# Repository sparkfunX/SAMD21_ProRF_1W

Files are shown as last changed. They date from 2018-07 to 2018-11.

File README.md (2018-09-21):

SparkFun SAMD21 Pro RF 1W 
========================================

SparkFun SAMD21 Pro RF 1W

[*SparkFun SAMD21 Pro RF 1W  (SPX-14984)*](https://www.sparkfun.com/products/14984)

LoRa stands for 'Long-Range,' referring to a modulation technique whose specialty is low power transmission of small data packets -- perfect for Internet of Things applications. Using either point-to-point radio or LoRaWAN you can send data from a node in a remote location back to your base station to check in on sensors or track equipment. Communication is possible in the other direction as well to send commands or control actuators!

Like the [LoRa®-enabled SparkX Pro RF](https://www.sparkfun.com/products/14785) this board is based on the Semtech SX1276 transceiver, but the module boasts a whopping 1W output power. All that extra oomph makes it possible to send small messages up to 9 miles using common rubber-duck type antennas. 

In addition to more transmission power the SparkX SAMD21 ProRF 1W gets more computational power courtesy of the SAMD21 microcontroller running at 48 MHz. We used the additional GPIO pins to permanently enable LoRaWAN signals. This means more pins for you to connect to sensors and actuators, even when connecting to a LoRaWAN network like [The Things Network](https://console.thethingsnetwork.org/). 

SparkFun labored with love to create this code. Feel like supporting open source hardware? 
Buy a [board](https://www.sparkfun.com/products/14984) from SparkFun!

Repository Contents
-------------------

* **/Documents** - Datasheets
* **/Hardware** - Eagle design files (.brd, .sch)

License Information
-------------------

This product is _**open source**_! 

If you have any questions or concerns on licensing, please contact techsupport@sparkfun.com.

Please use, reuse, and modify these files as you see fit. Please maintain attribution to SparkFun Electronics and release any derivative under the same license.

Distributed as-is; no warranty is given.

- Your friends at SparkFun.

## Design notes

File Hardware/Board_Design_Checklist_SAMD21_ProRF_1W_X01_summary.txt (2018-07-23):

1) Is there a SparkFun Logo? [YES]
comment: SPARKX logo

2) Is the board dimension outline correct thickness? (0.008 inch) [NO]
comment: 0.006

3) Are opposing 0.1 inch headers spaced to fit into a breadboard? [NO]
comment: Too wide, 90 degree rotated header section

4) Is the LED color standard followed? (red for power, blue for STAT, green for TX, yellow for RX) [YES]
comment: Used blue for lipo charge status

5) Does it pass DRC with top/bottom keepout layers on? [NO]
comment: Approved keepout errors

6) Are there airwires after ratsnest? [YES]
comment: Antenna, to be routed

7) Is the SparkFun Logo on the board? [YES]
comment: SparkX

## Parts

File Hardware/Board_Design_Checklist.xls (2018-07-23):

SECTION | CHECK | STATUS | DEPENDANCY | CORRECT ANSWER | USER | USER-ANSWER | COMMENT | WIKI_LINK
Macro | is_revision | 0
Macro | has_pth | 0
Macro | has_i2c | 0
Macro | has_SPI | 0
Macro | has_1x6_ftdi_header | 0
Macro | has_jumpers | 0
Macro | has_leds | 0
Macro | has_vreg | 0
Macro | has_QFN | 0
Macro | has_SS | 0
Macro | has_multi_sheet | 0
Macro | is_kit | 0
Macro | has_serial | 0
Macro | is_4layer | 0
Macro | has_milling | 0
Macro | has_switchorbutton | 0
Macro | has_collaboration | 0
General | Are the part libraries consistent with eagle github repo? |  |  | YES
Schematic | Is the proper frame with CC attribution used? |  |  | YES
Schematic | Are all schematic objects inside the frame? |  |  | YES
Schematic | Is there a SparkFun Logo? |  |  | YES
Schematic | Is there an OSHW logo? |  |  | YES
Schematic | Is proper attribution given to the original designer? |  |  | YES
Schematic | Is "Revised by: " and the reviser's name present? |  | 2 | YES
Schematic | Are NET labels the correct FLAG type? |  |  | YES
Schematic | Have all nets been drawn straight out from pin connections at least one grid space? |  |  | YES
Schematic | Are all net lines 0.006 inch? |  |  | YES
Schematic | Are there any 4-way junctions? |  |  | NO
Schematic | Are junction dots used for all 3-wire connections? |  |  | YES
Schematic | Are the fiducials in the lower right corner? |  |  | YES
Schematic | Are the standoffs in the lower right corner? |  |  | YES
Schematic | Are dashed grey lines ('info' eagle layer 97) used to clearly separate different areas? |  |  | YES
Schematic | Is the version number correct? |  |  | YES
Schematic | Is the version number included on all sheets? |  | 12 | YES
Schematic | Do all GND connections use the GND symbol (oriented downward)? |  |  | YES
Schematic | Do all VCC connections use the VCC symbol (oriented upward)? |  |  | YES
Schematic | Is the VCC range clearly labeled? |  |  | YES
Schematic | Are any jumpers labeled clearly by their function and possible settings? |  | 7 | YES
Schematic | Are any appropriate warnings (voltage conversion, sensitive I/O) labeled? |  |  | YES
Schematic | Are any notes of two versions of the board in the schematic (3.3V regulator vs 5V regulator)? |  |  | YES
Schematic | Do any part names have '/.~' in them? (Multiple sheets) |  | 12 | NO
Schematic | Have you verified that the BOM in Sparkle is accurate (also checking for PROD_ID, NAME, VALUE, PREFIX)? |  |  | YES
Schematic | Do any parts have unnecessary values (Eagle has autoset the package as the value)? |  |  | NO
Schematic | Regarding the voltage regulator, is the input on the LEFT, and the output on the RIGHT? |  | 9 | YES
Schematic | Is the I2C address in the schematic? |  | 4 | YES
Schematic | Is the I2C pin order correct (GND/VCC/SDA/CLK) and did you consider using a Qwiic connector? |  | 4 | YES |  |  |  | https://wiki.sparkfun.com/index.php?title=Eagle_Rules#Pin_Out.2FConnection_Orientation
Schematic | Is the I2C pull-up resistor isolation jumper present? |  | 4 | YES |  |  |  | https://wiki.sparkfun.com/index.php?title=Eagle_Rules#Component_Placement
Schematic | Is the SPI pull-up resistor for Chip Select present? |  | 5 | YES |  |  |  | https://wiki.sparkfun.com/index.php?title=Eagle_Rules#Component_Placement
Schematic | Is the MISO tri-state buffer included? |  | 5 | YES |  |  |  | https://wiki.sparkfun.com/index.php?title=Eagle_Rules#Component_Placement
Board | If this is a Qwiic board, does it follow the design guidelines for Qwiic boards in the Wiki? |  | 4 | YES |  |  |  | https://wiki.sparkfun.com/index.php?title=Qwiic_Standard
Board | If this board is not branded as a Qwicc board, but contains a Qwiic connector, is the connector labeled with “QWIIC” text silk? |  | 4
Board | Are the inner layers on the correct eagle layers? (2 and 15) |  | 15 | YES |  |  |  | https://wiki.sparkfun.com/index.php?title=Eagle_Rules#Board_Creation.2C_Outline
Board | Does your 4 layer board include '1' '2' '3' '4' in the copper of each layer? |  | 15 | YES |  |  |  | https://wiki.sparkfun.com/index.php?title=Eagle_Rules#Board_Creation.2C_Outline
Board | Is the bottom left corner board dimensions at 0,0? |  |  | YES |  |  |  | https://wiki.sparkfun.com/index.php?title=Eagle_Rules#Board_Creation.2C_Outline
Board | Is the board dimension outline correct thickness? (0.008 inch) |  |  | YES |  |  |  | https://wiki.sparkfun.com/index.php?title=Eagle_Rules#Board_Creation.2C_Outline
Board | If this requires very precise dimensions (e.g. USB stick), did you consider GP's tolerances? (dimension=5mils, Vscore=10mils) |  |  |  |  |  |  | https://wiki.sparkfun.com/index.php?title=Eagle_Rules#Fab_house_Tolerances
Board | Are 0.1 inch headers lined up on 0.1 inch grid? |  |  | YES |  |  |  | https://wiki.sparkfun.com/index.php?title=Eagle_Rules#Board_Creation.2C_Outline
Board | Are opposing 0.1 inch headers spaced to fit into a breadboard? |  |  | YES |  |  |  | https://wiki.sparkfun.com/index.php?title=Eagle_Rules#Board_Creation.2C_Outline
Board | Do all testpoints have a separation of at least 0.1 inch (preferably placed on a 0.05 inch grid)? |  |  | YES |  |  |  | https://wiki.sparkfun.com/index.php?title=Eagle_Rules#Board_Creation.2C_Outline
Board | Does the board have standoffs? |  |  | YES |  |  |  | https://wiki.sparkfun.com/index.php?title=Eagle_Rules#Board_Creation.2C_Outline
Board | Can standoffs/screws be used clear of other parts? |  |  | YES |  |  |  | https://wiki.sparkfun.com/index.php?title=Eagle_Rules#Board_Creation.2C_Outline
Board | Is the FTDI connector accessible (do neighboring parts allow enough space to clear each side)? |  | 6 | YES |  |  |  | https://wiki.sparkfun.com/index.php?title=Eagle_Rules#Pin_Out.2FConnection_Orientation
Board | Is the FTDI connector oriented so the FTDI breakout can be slid on properly (IC side up, header side down)? |  | 6 | YES |  |  |  | https://wiki.sparkfun.com/index.php?title=Eagle_Rules#Pin_Out.2FConnection_Orientation
Board | Are vias tented correctly? |  |  | YES |  |  |  | https://wiki.sparkfun.com/index.php?title=Eagle_Rules#Trace_Routing.2C_Polygon_Pours.2C_and_Vias
Board | If possible, are all overhanging parts on the same edge of the board (this helps with panelization)? |  |  | YES |  |  |  | https://wiki.sparkfun.com/index.php?title=Eagle_Rules#Pin_Out.2FConnection_Orientation
Board | If this design requires special ordering or production assembly instructions, have the symbols/packages been added with notes? (PCB thickness, humidity sensitivity, etc.) |  |  | YES
Board | Are any vias intended to be used as PTH headers (they shouldn't be)? |  |  | NO |  |  |  | https://wiki.sparkfun.com/index.php?title=Eagle_Rules#Trace_Routing.2C_Polygon_Pours.2C_and_Vias
Board | Is the LED color standard followed? (red for power, blue for STAT, green for TX, yellow for RX) |  | 8 | YES |  |  |  | https://wiki.sparkfun.com/index.php?title=Eagle_Rules#Component_Placement
Board | Do parts that need selective solder have a planned nozzle path on layer 48? (valid widths: 0.178", 0,263", 0.354") |  | 11 | YES |  |  |  | https://wiki.sparkfun.com/index.php?title=Eagle_Rules#Selective_Soldering
Board | As best as possible, do all SMD pads have only 1 trace entering the pad? |  |  | YES |  |  |  | https://wiki.sparkfun.com/index.php?title=Eagle_Rules#PCB_Layout
Board | Are there any natural bridges on SMT components? |  |  | NO |  |  |  | https://wiki.sparkfun.com/index.php?title=Eagle_Rules#PCB_Layout
Board | Do V-Scored edges have a 50 mil border free of pads and parts (to prevent cracking on separation)? |  |  | YES
Board | Is the direction of TX/RX serial connections correct? |  | 14 | YES
Board | Are the TX/RX pins of the FTDI properly connected? |  | 6 | YES
Board | Is trace routing up to spec? (to/from center-points, straight lines, 45 angles, 'T' intersections, no right angles or acid traps) |  |  | YES |  |  |  | https://wiki.sparkfun.com/index.php?title=Eagle_Rules#PCB_Layout
Board | For thermal considerations, are traces routed away from the component, with symmetrical routing? |  | 10 | YES
Board | Do all footprints pass 1:1 check? (Applies mostly to new components) |  |  | YES
Board | Are all QFN components with 6 or more leads 75 percent pasted on lead pads? (May be contended depending on performance) |  | 10 | YES |  |  |  | https://wiki.sparkfun.com/index.php?title=Eagle_Rules#Footprints.2FPackages
Board | Are center pad cream apertures properly reduced? (50-75% paste is good) |  | 10 | YES |  |  |  | https://wiki.sparkfun.com/index.php?title=Eagle_Rules#Footprints.2FPackages
Board | Is there solder mask between pads on of 11 mil separation and greater? |  |  | YES |  |  |  | https://wiki.sparkfun.com/index.php?title=Eagle_Rules#Fab_house_Tolerances
Board | Is there a correct version number in the copper (aligned properly with the edge of the PCB)? |  |  | YES
Board | Are there fiducials on both the TOP and BOTTOM of the board? |  |  | YES
Board | Does it pass DRC with top/bottom keepout layers on? |  |  | YES
Board | If there are any DRC errors, have they all been approved? |  |  | YES
Board | Are there airwires after ratsnest? |  |  | NO
Board | Are all KIT PTH parts on the correct side with correct masking (e.g. the TSTOP or BSTOP expose the correct side) |  | 13 | YES
Documentation | Is there a note for a 4-layer board (on tDOCU)? |  | 15 | YES
Documentation | Do all packages have NAME and VALUE? |  |  | YES
Documentation | Is there a note for a board thickness other than 0.63 inch?
Documentation | Are measurements included for outer dimension and standoffs (Eagle layer 47)? |  |  | YES
Documentation | Are the board dimensions on 0.05 inch or 0.01 inch grid? |  |  | YES
Documentation | Are routed-out areas labeled 'ROUTE OUT' (on dimension)? |  | 16 | YES
Documentation | Is the CC/Design By included in tDocu? |  |  | YES
Documentation | Is the designer name included in tDocu? |  |  | YES
Documentation | Is 'Revised by:' and 'Revisor Name' included in tDocu? |  | 2 | YES
Silkscreen/Labeling | Is the name of the board on the board? |  |  | YES |  |  |  | https://wiki.sparkfun.com/index.php?title=Eagle_Rules#PCB_Silk
Silkscreen/Labeling | Do all footprints have 0.008 inch silk footprint? |  |  | YES
Silkscreen/Labeling | Are all LEDs labeled with their purpose? |  | 8 | YES
Silkscreen/Labeling | Are all PTHs (aka connectors) clearly labeled with their purpose on both sides of the board? |  |  | YES
Silkscreen/Labeling | Are battery terminals labeled +/- correctly? |  |  | YES
Silkscreen/Labeling | Are all jumpers labeled? |  | 7 | YES
Silkscreen/Labeling | If it is a 3-way jumper, is there a label on each side of the jumper? |  | 7 | YES
Silkscreen/Labeling | Are all switches/buttons labeled properly? |  | 17 | YES
Silkscreen/Labeling | Are active low pins labeled clearly? |  |  | YES
Silkscreen/Labeling | Are all labels lined up properly? |  |  | YES
Silkscreen/Labeling | Is all text at least 0.032 inch, 15 percent radio, and vector? |  |  | YES
Silkscreen/Labeling | Does the FTDI connector have BLK/GRN labeled correctly? |  | 6 | YES
Silkscreen/Labeling | Do all components have polarity or pin 1 labeled? |  |  | YES
Silkscreen/Labeling | Is the polarity label outside of the package for visibility after part population? |  |  | YES
Silkscreen/Labeling | Are there check labels for different versions of the board (3.3V vs 5V)? |  |  | YES
Silkscreen/Labeling | Is the SparkFun Logo on the board? |  |  | YES
Silkscreen/Labeling | Is the OSHW logo on the board? |  |  | YES
Silkscreen/Labeling | Is the firmware opensource? If not, did you omit the OSHW Logo? |  | 18 | YES
Silkscreen/Labeling | Is any silkscreen overlaid on vias? |  |  | NO
Silkscreen/Labeling | Is there a URL for any kits or unique boards?
Special | Are dimension lines properly spaced for V-scoring (lines on a 0.020” center-to-center spacing)?
Special | On white solder mask pcbs, is there any solder mask between leads on large SMT components?
Special | Are axes labeled correctly?
Special | Are there warning labels for high voltage areas?
END | Thanks for flying with us. Have a great day!!

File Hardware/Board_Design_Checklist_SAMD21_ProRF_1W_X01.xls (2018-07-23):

SECTION | CHECK | STATUS | DEPENDANCY | CORRECT ANSWER | USER | USER-ANSWER | COMMENT | WIKI_LINK
Macro | is_revision | 0
Macro | has_pth | 0
Macro | has_i2c | 0
Macro | has_SPI | 1
Macro | has_1x6_ftdi_header | 0
Macro | has_jumpers | 0
Macro | has_leds | 1
Macro | has_vreg | 1
Macro | has_QFN | 0
Macro | has_SS | 0
Macro | has_multi_sheet | 0
Macro | is_kit | 0
Macro | has_serial | 1
Macro | is_4layer | 0
Macro | has_milling | 0
Macro | has_switchorbutton | 1
Macro | has_collaboration | 0
General | Are the part libraries consistent with eagle github repo? |  |  | YES | owen.lyke | YES
Schematic | Is the proper frame with CC attribution used? |  |  | YES | owen.lyke | YES
Schematic | Are all schematic objects inside the frame? |  |  | YES | owen.lyke | YES
Schematic | Is there a SparkFun Logo? |  |  | YES | owen.lyke | YES | SPARKX logo
Schematic | Is there an OSHW logo? |  |  | YES | owen.lyke | YES
Schematic | Is proper attribution given to the original designer? |  |  | YES | owen.lyke | YES
Schematic | Is "Revised by: " and the reviser's name present? |  | 2 | YES | owen.lyke | *n/a*
Schematic | Are NET labels the correct FLAG type? |  |  | YES | owen.lyke | YES
Schematic | Have all nets been drawn straight out from pin connections at least one grid space? |  |  | YES | owen.lyke | YES
Schematic | Are all net lines 0.006 inch? |  |  | YES | owen.lyke | YES
Schematic | Are there any 4-way junctions? |  |  | NO | owen.lyke | YES
Schematic | Are junction dots used for all 3-wire connections? |  |  | YES | owen.lyke | YES
Schematic | Are the fiducials in the lower right corner? |  |  | YES | owen.lyke | YES
Schematic | Are the standoffs in the lower right corner? |  |  | YES | owen.lyke | NO
Schematic | Are dashed grey lines ('info' eagle layer 97) used to clearly separate different areas? |  |  | YES | owen.lyke | YES
Schematic | Is the version number correct? |  |  | YES | owen.lyke | YES
Schematic | Is the version number included on all sheets? |  | 12 | YES | owen.lyke | *n/a*
Schematic | Do all GND connections use the GND symbol (oriented downward)? |  |  | YES | owen.lyke | YES
Schematic | Do all VCC connections use the VCC symbol (oriented upward)? |  |  | YES | owen.lyke | YES
Schematic | Is the VCC range clearly labeled? |  |  | YES | owen.lyke | YES
Schematic | Are any jumpers labeled clearly by their function and possible settings? |  | 7 | YES | owen.lyke | *n/a*
Schematic | Are any appropriate warnings (voltage conversion, sensitive I/O) labeled? |  |  | YES | owen.lyke | YES
Schematic | Are any notes of two versions of the board in the schematic (3.3V regulator vs 5V regulator)? |  |  | YES | owen.lyke | n/a
Schematic | Do any part names have '/.~' in them? (Multiple sheets) |  | 12 | NO | owen.lyke | *n/a*
Schematic | Have you verified that the BOM in Sparkle is accurate (also checking for PROD_ID, NAME, VALUE, PREFIX)? |  |  | YES | owen.lyke | n/a
Schematic | Do any parts have unnecessary values (Eagle has autoset the package as the value)? |  |  | NO | owen.lyke | NO
Schematic | Regarding the voltage regulator, is the input on the LEFT, and the output on the RIGHT? |  | 9 | YES | owen.lyke | YES
Schematic | Is the I2C address in the schematic? |  | 4 | YES | owen.lyke | *n/a*
Schematic | Is the I2C pin order correct (GND/VCC/SDA/CLK) and did you consider using a Qwiic connector? |  | 4 | YES | owen.lyke | *n/a* |  | https://wiki.sparkfun.com/index.php?title=Eagle_Rules#Pin_Out.2FConnection_Orientation
Schematic | Is the I2C pull-up resistor isolation jumper present? |  | 4 | YES | owen.lyke | *n/a* |  | https://wiki.sparkfun.com/index.php?title=Eagle_Rules#Component_Placement
Schematic | Is the SPI pull-up resistor for Chip Select present? |  | 5 | YES | owen.lyke | YES |  | https://wiki.sparkfun.com/index.php?title=Eagle_Rules#Component_Placement
Schematic | Is the MISO tri-state buffer included? |  | 5 | YES | owen.lyke | NO |  | https://wiki.sparkfun.com/index.php?title=Eagle_Rules#Component_Placement
Board | If this is a Qwiic board, does it follow the design guidelines for Qwiic boards in the Wiki? |  | 4 | YES | owen.lyke | *n/a* |  | https://wiki.sparkfun.com/index.php?title=Qwiic_Standard
Board | If this board is not branded as a Qwicc board, but contains a Qwiic connector, is the connector labeled with “QWIIC” text silk? |  | 4 |  | owen.lyke | NO
Board | Are the inner layers on the correct eagle layers? (2 and 15) |  | 15 | YES | owen.lyke | *n/a* |  | https://wiki.sparkfun.com/index.php?title=Eagle_Rules#Board_Creation.2C_Outline
Board | Does your 4 layer board include '1' '2' '3' '4' in the copper of each layer? |  | 15 | YES | owen.lyke | *n/a* |  | https://wiki.sparkfun.com/index.php?title=Eagle_Rules#Board_Creation.2C_Outline
Board | Is the bottom left corner board dimensions at 0,0? |  |  | YES | owen.lyke | YES |  | https://wiki.sparkfun.com/index.php?title=Eagle_Rules#Board_Creation.2C_Outline
Board | Is the board dimension outline correct thickness? (0.008 inch) |  |  | YES | owen.lyke | NO | 0.006 | https://wiki.sparkfun.com/index.php?title=Eagle_Rules#Board_Creation.2C_Outline
Board | If this requires very precise dimensions (e.g. USB stick), did you consider GP's tolerances? (dimension=5mils, Vscore=10mils) |  |  |  | owen.lyke | n/a |  | https://wiki.sparkfun.com/index.php?title=Eagle_Rules#Fab_house_Tolerances
Board | Are 0.1 inch headers lined up on 0.1 inch grid? |  |  | YES | owen.lyke | YES |  | https://wiki.sparkfun.com/index.php?title=Eagle_Rules#Board_Creation.2C_Outline
Board | Are opposing 0.1 inch headers spaced to fit into a breadboard? |  |  | YES | owen.lyke | NO | Too wide, 90 degree rotated header section | https://wiki.sparkfun.com/index.php?title=Eagle_Rules#Board_Creation.2C_Outline
Board | Do all testpoints have a separation of at least 0.1 inch (preferably placed on a 0.05 inch grid)? |  |  | YES | owen.lyke | n/a |  | https://wiki.sparkfun.com/index.php?title=Eagle_Rules#Board_Creation.2C_Outline
Board | Does the board have standoffs? |  |  | YES | owen.lyke | NO |  | https://wiki.sparkfun.com/index.php?title=Eagle_Rules#Board_Creation.2C_Outline
Board | Can standoffs/screws be used clear of other parts? |  |  | YES | owen.lyke | n/a |  | https://wiki.sparkfun.com/index.php?title=Eagle_Rules#Board_Creation.2C_Outline
Board | Is the FTDI connector accessible (do neighboring parts allow enough space to clear each side)? |  | 6 | YES | owen.lyke | *n/a* |  | https://wiki.sparkfun.com/index.php?title=Eagle_Rules#Pin_Out.2FConnection_Orientation
Board | Is the FTDI connector oriented so the FTDI breakout can be slid on properly (IC side up, header side down)? |  | 6 | YES | owen.lyke | *n/a* |  | https://wiki.sparkfun.com/index.php?title=Eagle_Rules#Pin_Out.2FConnection_Orientation
Board | Are vias tented correctly? |  |  | YES | owen.lyke | YES |  | https://wiki.sparkfun.com/index.php?title=Eagle_Rules#Trace_Routing.2C_Polygon_Pours.2C_and_Vias
Board | If possible, are all overhanging parts on the same edge of the board (this helps with panelization)? |  |  | YES | owen.lyke | YES |  | https://wiki.sparkfun.com/index.php?title=Eagle_Rules#Pin_Out.2FConnection_Orientation
Board | If this design requires special ordering or production assembly instructions, have the symbols/packages been added with notes? (PCB thickness, humidity sensitivity, etc.) |  |  | YES | owen.lyke | YES
Board | Are any vias intended to be used as PTH headers (they shouldn't be)? |  |  | NO | owen.lyke | NO |  | https://wiki.sparkfun.com/index.php?title=Eagle_Rules#Trace_Routing.2C_Polygon_Pours.2C_and_Vias
Board | Is the LED color standard followed? (red for power, blue for STAT, green for TX, yellow for RX) |  | 8 | YES | owen.lyke | YES | Used blue for lipo charge status | https://wiki.sparkfun.com/index.php?title=Eagle_Rules#Component_Placement
Board | Do parts that need selective solder have a planned nozzle path on layer 48? (valid widths: 0.178", 0,263", 0.354") |  | 11 | YES | owen.lyke | *n/a* |  | https://wiki.sparkfun.com/index.php?title=Eagle_Rules#Selective_Soldering
Board | As best as possible, do all SMD pads have only 1 trace entering the pad? |  |  | YES | owen.lyke | YES |  | https://wiki.sparkfun.com/index.php?title=Eagle_Rules#PCB_Layout
Board | Are there any natural bridges on SMT components? |  |  | NO | owen.lyke | NO |  | https://wiki.sparkfun.com/index.php?title=Eagle_Rules#PCB_Layout
Board | Do V-Scored edges have a 50 mil border free of pads and parts (to prevent cracking on separation)? |  |  | YES | owen.lyke | n/a
Board | Is the direction of TX/RX serial connections correct? |  | 14 | YES | owen.lyke | n/a
Board | Are the TX/RX pins of the FTDI properly connected? |  | 6 | YES | owen.lyke | *n/a*
Board | Is trace routing up to spec? (to/from center-points, straight lines, 45 angles, 'T' intersections, no right angles or acid traps) |  |  | YES | owen.lyke | YES |  | https://wiki.sparkfun.com/index.php?title=Eagle_Rules#PCB_Layout
Board | For thermal considerations, are traces routed away from the component, with symmetrical routing? |  | 10 | YES | owen.lyke | *n/a*
Board | Do all footprints pass 1:1 check? (Applies mostly to new components) |  |  | YES | owen.lyke | YES
Board | Are all QFN components with 6 or more leads 75 percent pasted on lead pads? (May be contended depending on performance) |  | 10 | YES | owen.lyke | *n/a* |  | https://wiki.sparkfun.com/index.php?title=Eagle_Rules#Footprints.2FPackages
Board | Are center pad cream apertures properly reduced? (50-75% paste is good) |  | 10 | YES | owen.lyke | *n/a* |  | https://wiki.sparkfun.com/index.php?title=Eagle_Rules#Footprints.2FPackages
Board | Is there solder mask between pads on of 11 mil separation and greater? |  |  | YES | owen.lyke | YES |  | https://wiki.sparkfun.com/index.php?title=Eagle_Rules#Fab_house_Tolerances
Board | Is there a correct version number in the copper (aligned properly with the edge of the PCB)? |  |  | YES | owen.lyke | YES
Board | Are there fiducials on both the TOP and BOTTOM of the board? |  |  | YES | owen.lyke | YES
Board | Does it pass DRC with top/bottom keepout layers on? |  |  | YES | owen.lyke | NO | Approved keepout errors
Board | If there are any DRC errors, have they all been approved? |  |  | YES | owen.lyke | YES
Board | Are there airwires after ratsnest? |  |  | NO | owen.lyke | YES | Antenna, to be routed
Board | Are all KIT PTH parts on the correct side with correct masking (e.g. the TSTOP or BSTOP expose the correct side) |  | 13 | YES | owen.lyke | *n/a*
Documentation | Is there a note for a 4-layer board (on tDOCU)? |  | 15 | YES | owen.lyke | *n/a*
Documentation | Do all packages have NAME and VALUE? |  |  | YES | owen.lyke | YES
Documentation | Is there a note for a board thickness other than 0.63 inch? |  |  |  | owen.lyke | YES
Documentation | Are measurements included for outer dimension and standoffs (Eagle layer 47)? |  |  | YES | owen.lyke | n/a
Documentation | Are the board dimensions on 0.05 inch or 0.01 inch grid? |  |  | YES | owen.lyke | YES
Documentation | Are routed-out areas labeled 'ROUTE OUT' (on dimension)? |  | 16 | YES | owen.lyke | *n/a*
Documentation | Is the CC/Design By included in tDocu? |  |  | YES | owen.lyke | YES
Documentation | Is the designer name included in tDocu? |  |  | YES | owen.lyke | YES
Documentation | Is 'Revised by:' and 'Revisor Name' included in tDocu? |  | 2 | YES | owen.lyke | *n/a*
Silkscreen/Labeling | Is the name of the board on the board? |  |  | YES | owen.lyke | YES |  | https://wiki.sparkfun.com/index.php?title=Eagle_Rules#PCB_Silk
Silkscreen/Labeling | Do all footprints have 0.008 inch silk footprint? |  |  | YES | owen.lyke | YES
Silkscreen/Labeling | Are all LEDs labeled with their purpose? |  | 8 | YES | owen.lyke | YES
Silkscreen/Labeling | Are all PTHs (aka connectors) clearly labeled with their purpose on both sides of the board? |  |  | YES | owen.lyke | YES
Silkscreen/Labeling | Are battery terminals labeled +/- correctly? |  |  | YES | owen.lyke | YES
Silkscreen/Labeling | Are all jumpers labeled? |  | 7 | YES | owen.lyke | *n/a*
Silkscreen/Labeling | If it is a 3-way jumper, is there a label on each side of the jumper? |  | 7 | YES | owen.lyke | *n/a*
Silkscreen/Labeling | Are all switches/buttons labeled properly? |  | 17 | YES | owen.lyke | YES
Silkscreen/Labeling | Are active low pins labeled clearly? |  |  | YES | owen.lyke | YES
Silkscreen/Labeling | Are all labels lined up properly? |  |  | YES | owen.lyke | YES
Silkscreen/Labeling | Is all text at least 0.032 inch, 15 percent radio, and vector? |  |  | YES | owen.lyke | YES
Silkscreen/Labeling | Does the FTDI connector have BLK/GRN labeled correctly? |  | 6 | YES | owen.lyke | *n/a*
Silkscreen/Labeling | Do all components have polarity or pin 1 labeled? |  |  | YES | owen.lyke | YES
Silkscreen/Labeling | Is the polarity label outside of the package for visibility after part population? |  |  | YES | owen.lyke | YES
Silkscreen/Labeling | Are there check labels for different versions of the board (3.3V vs 5V)? |  |  | YES | owen.lyke | n/a
Silkscreen/Labeling | Is the SparkFun Logo on the board? |  |  | YES | owen.lyke | YES | SparkX
Silkscreen/Labeling | Is the OSHW logo on the board? |  |  | YES | owen.lyke | YES
Silkscreen/Labeling | Is the firmware opensource? If not, did you omit the OSHW Logo? |  | 18 | YES | owen.lyke | *n/a*
Silkscreen/Labeling | Is any silkscreen overlaid on vias? |  |  | NO | owen.lyke | YES
Silkscreen/Labeling | Is there a URL for any kits or unique boards? |  |  |  | owen.lyke | n/a
Special | Are dimension lines properly spaced for V-scoring (lines on a 0.020” center-to-center spacing)? |  |  |  | owen.lyke | n/a
Special | On white solder mask pcbs, is there any solder mask between leads on large SMT components? |  |  |  | owen.lyke | n/a
Special | Are axes labeled correctly? |  |  |  | owen.lyke | n/a
Special | Are there warning labels for high voltage areas? |  |  |  | owen.lyke | n/a
END | Thanks for flying with us. Have a great day!! |  |  |  | owen.lyke | YES

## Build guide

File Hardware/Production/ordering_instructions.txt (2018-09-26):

panel size, 129x96mm
PCB thickness, 1.6mm
number of layers, 2
soldermask color, Black
silkscreen color, White
oz copper, 1oz
finish, HASL lead free
stencils, top+bottom
pcs per panel, 4

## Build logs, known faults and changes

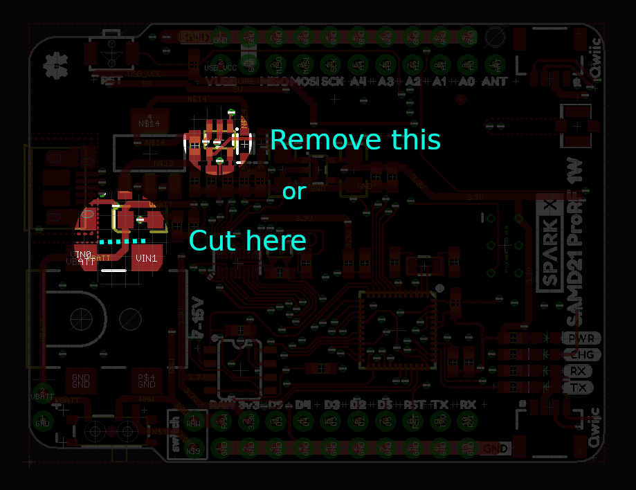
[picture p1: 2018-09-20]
Documents/Errata/CutTrace.PNG

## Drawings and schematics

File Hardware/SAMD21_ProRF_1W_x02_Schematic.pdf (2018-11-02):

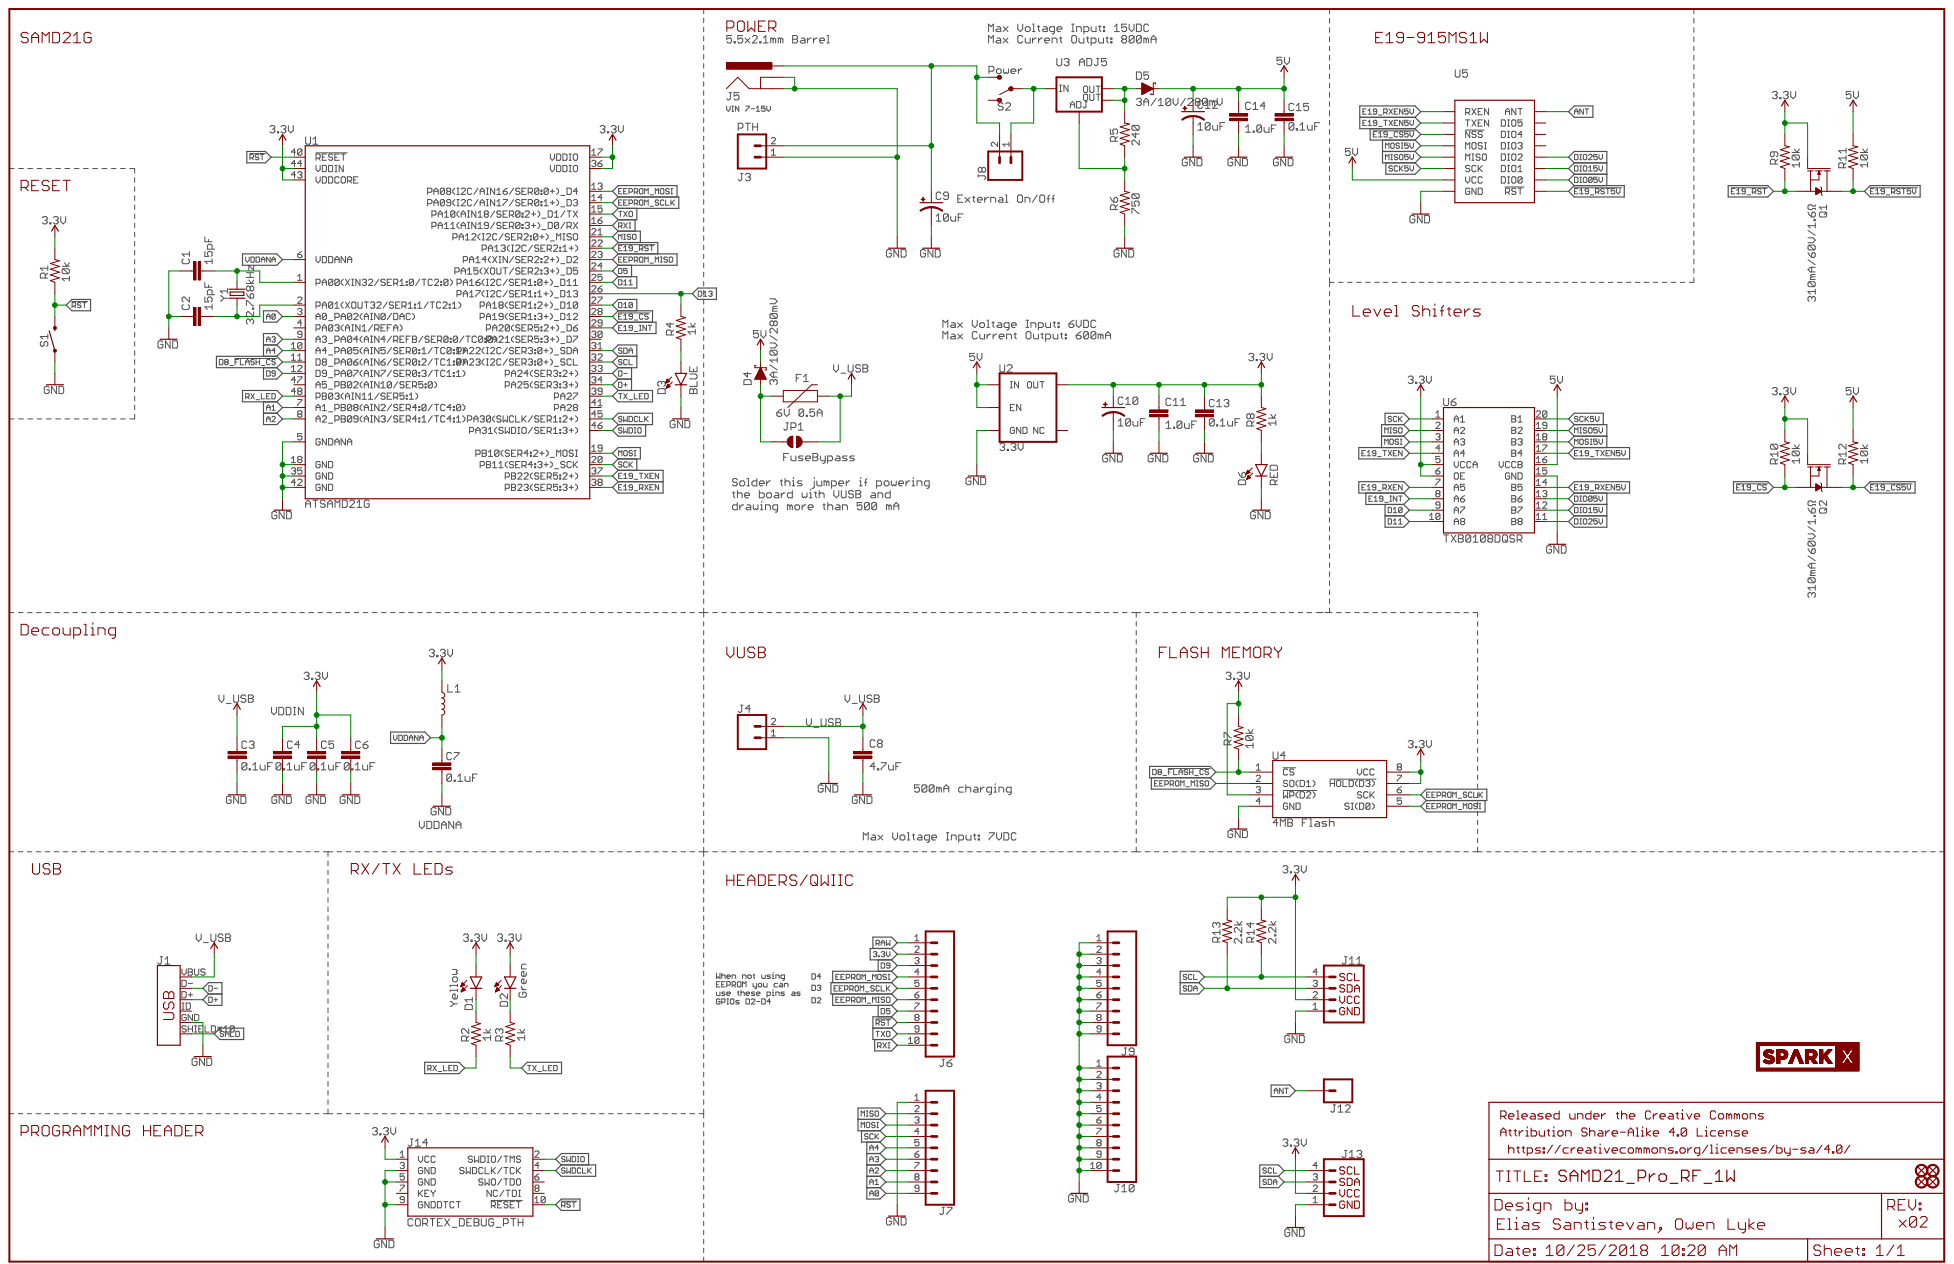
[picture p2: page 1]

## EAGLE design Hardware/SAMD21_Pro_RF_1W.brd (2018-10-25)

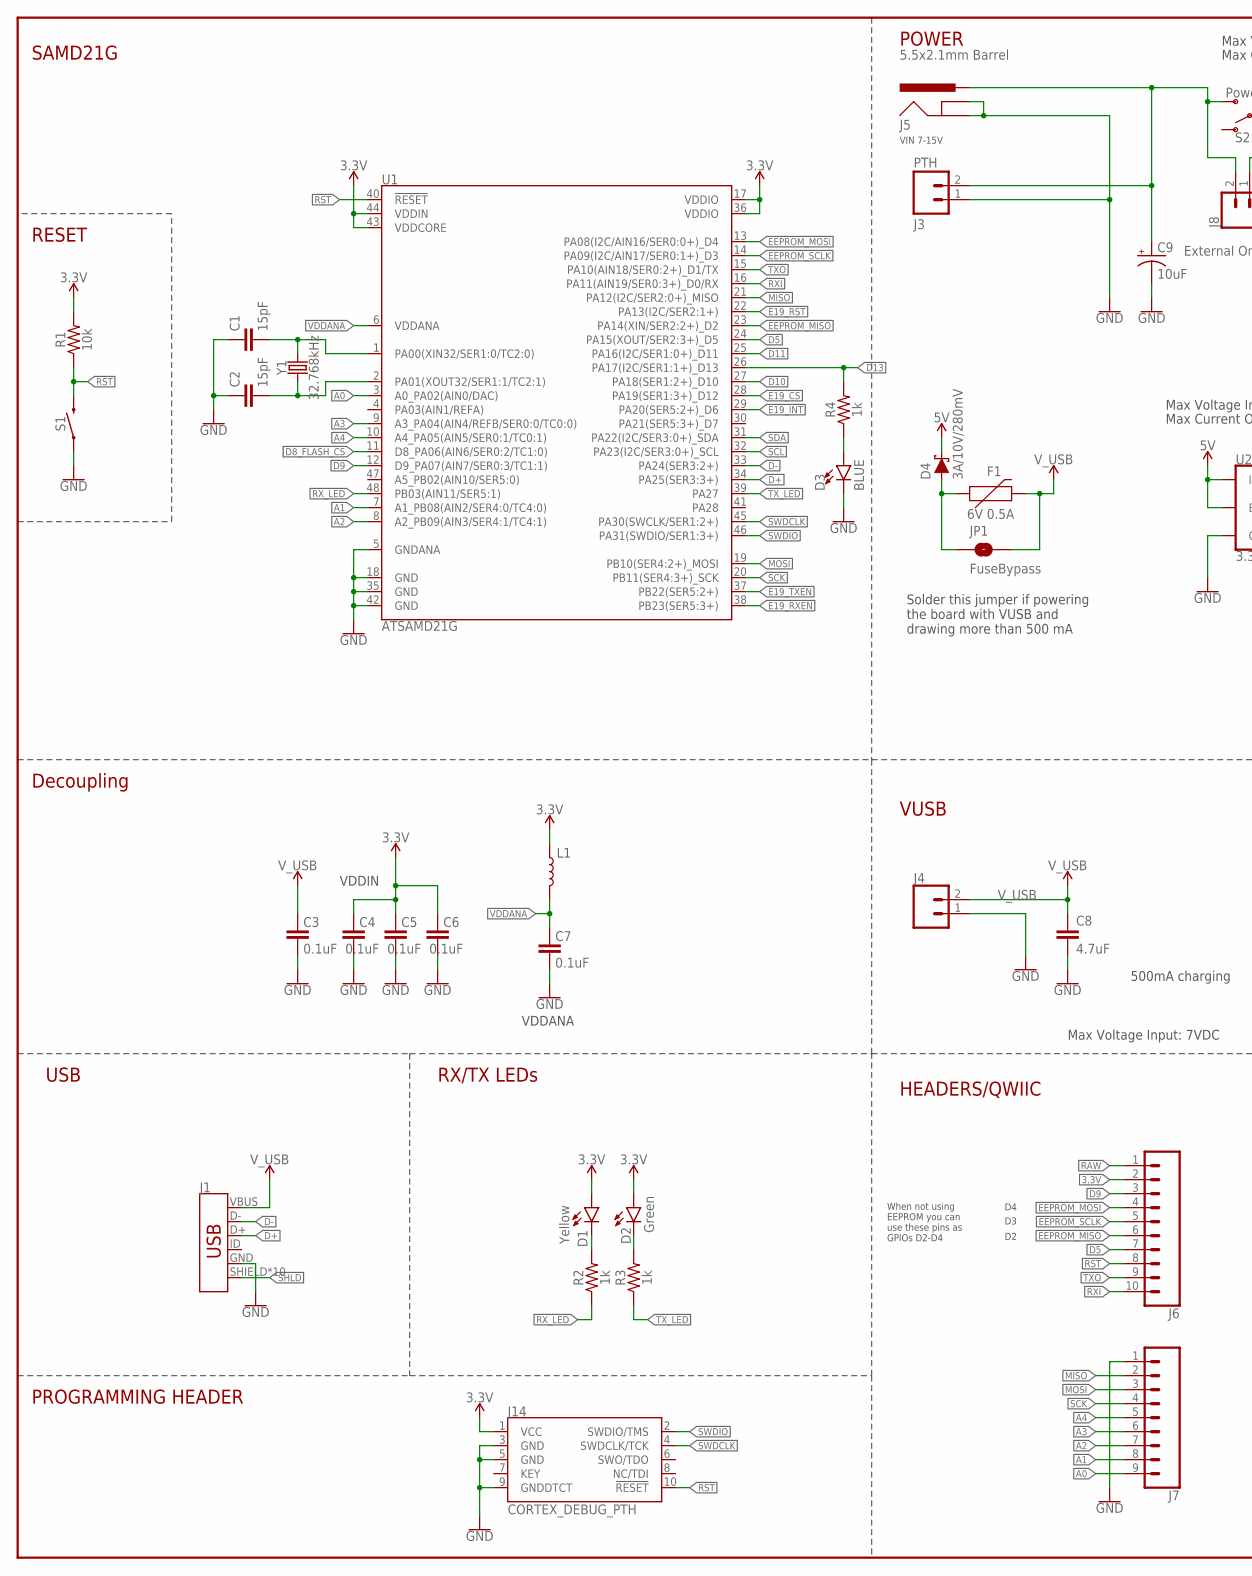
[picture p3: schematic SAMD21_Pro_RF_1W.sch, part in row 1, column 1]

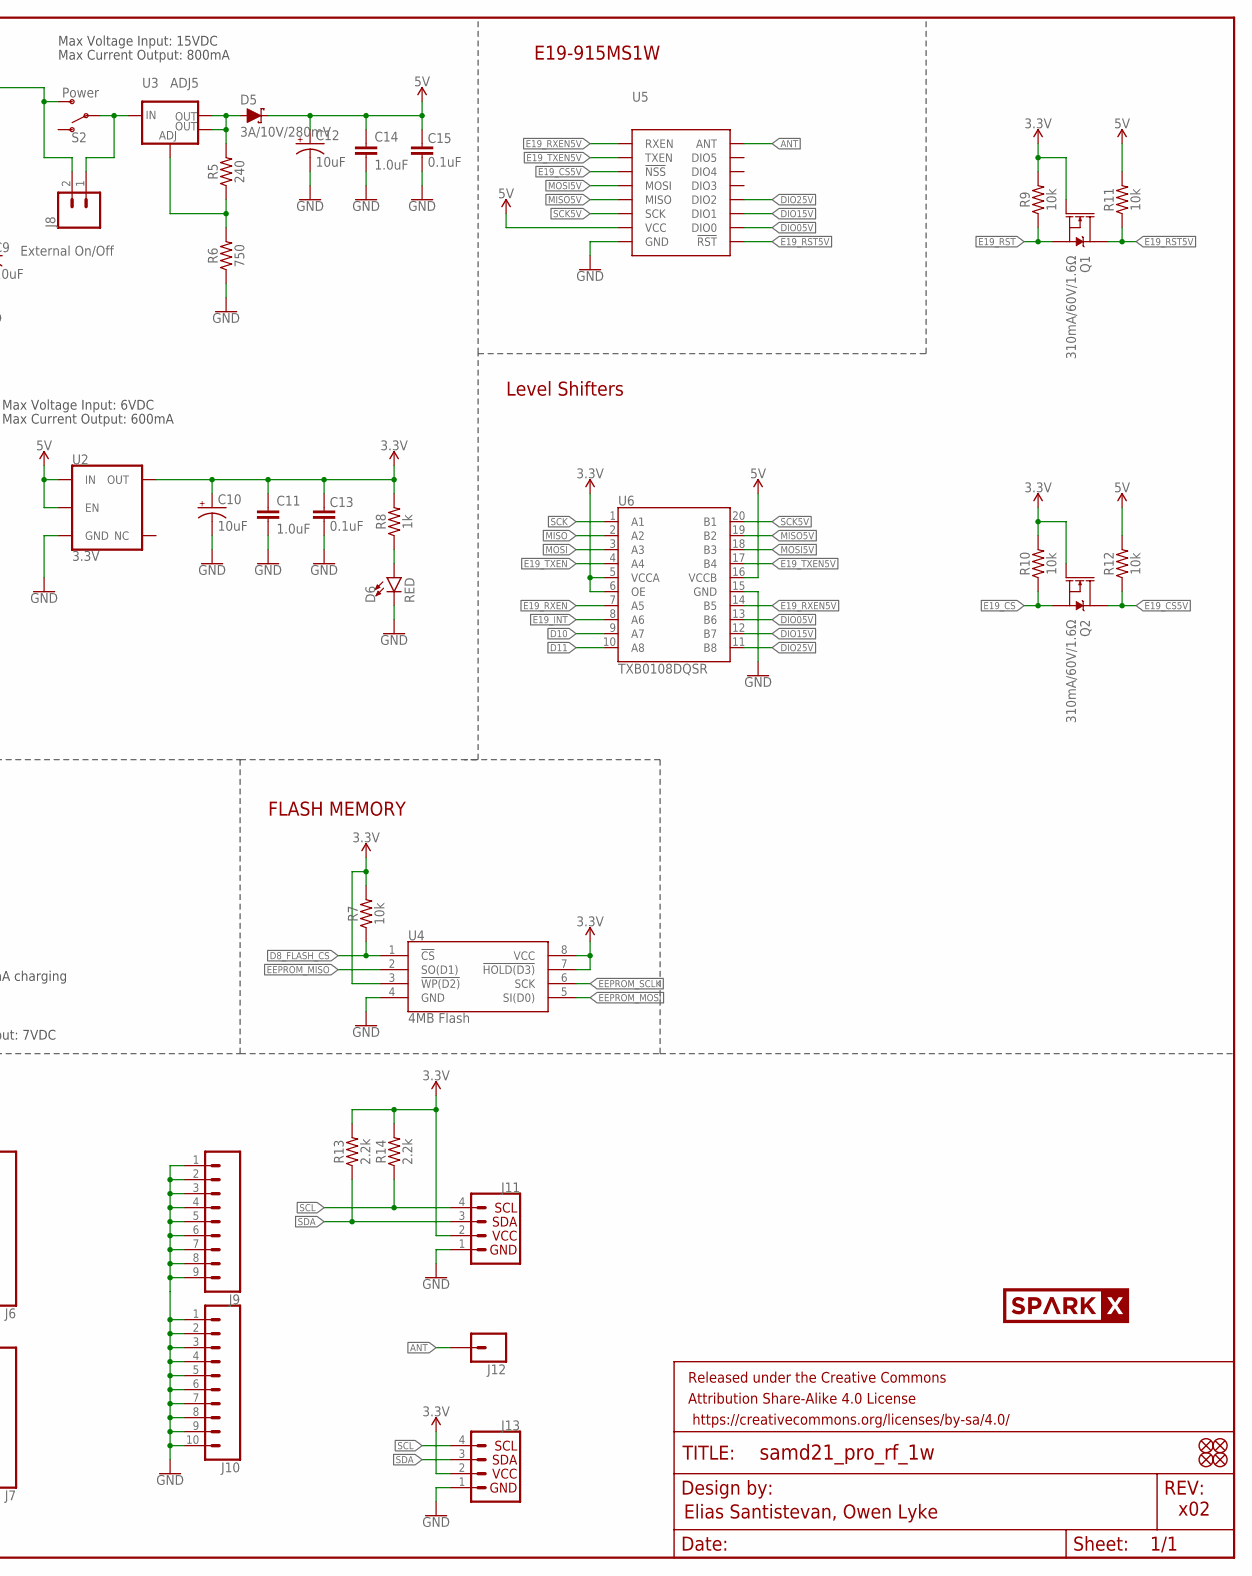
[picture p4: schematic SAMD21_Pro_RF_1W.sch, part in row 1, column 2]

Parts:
C1, C2: 15pF; 0603
C3, C4, C5, C6, C7, C13, C15: 0.1uF; 0603
C8: 4.7uF; 0603
C9, C10, C12: 10uF; EIA3216
C11, C14: 1.0uF; 0603
D1: Yellow; LED-0603
D2: Green; LED-0603
D3: BLUE; LED-0603
D4, D5: 3A/10V/280mV; SOD-323
D6: RED; LED-0603
F1: 6V 0.5A; 0805
FD1, FD2, FD3, FD4: FIDUCIAL1X2; FIDUCIAL-1X2
FRAME1: FRAME-LEDGER; CREATIVE_COMMONS
J1: USB_MICRO-B_HALF_PTH_MILL; USB-MICROB-PTH-MILL
J3: PTH; 1X02_NO_SILK
J4: CONN_021X02_NO_SILK; 1X02_NO_SILK
J5: 5.5x2.1mm Barrel; POWER_JACK_SMD
J6, J10: CONN_10NO_SILK_PTH_FEMALE; 1X10_NO_SILK
J7, J9: CONN_09NO_SILK; 1X09_NO_SILK
J8: External On/Off; 1X02_NO_SILK
J11, J13: QWIIC_CONNECTORJS-1MM; 1X04_1MM_RA
J12: CONN_01PTH_NO_SILK_YES_STOP; 1X01_NO_SILK
J14: CORTEX_DEBUG_PTH; 2X5-PTH-1.27MM
JP1: FuseBypass; SMT-JUMPER_2_NO_SILK
L1: INDUCTORFB-30OHM; 0603
Q1, Q2: 310mA/60V/1.6Ω; SOT323
R1, R7, R9, R10, R11, R12: 10k; 0603
R2, R3, R4, R8: 1k; 0603
R5: 240; 0603
R6: 750; 0603
R13, R14: 2.2k; 0603
S1: MOMENTARY-SWITCH-SPST-SMD-5.2-REDUNDANT; TACTILE_SWITCH_SMD_5.2MM
S2: Power; SWITCH_SPST_SMD_A
U1: ATSAMD21G; QFN-48_NO_EXPOSED_PAD
U2: 3.3V; SOT23-5
U3: ADJ5; SOT223
U4: 4MB Flash; SO08
U5: E19-915MS1W
U6: TXB0108DQSR; UFDFN-20
U$34: SPARKX-LOGO4; SPARKX-MEDIUM
Y1: 32.768kHz; CRYSTAL-SMD-3.2X1.5MM

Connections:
3.3V: C4.2, C5.2, C6.2, C10.+, C11.1, C13.2, D1.A, D2.A, J6.2, J11.2, J13.2, J14.1 (VCC), L1.1, Q1.1 (G), Q2.1 (G), R1.2, R7.2, R8.2, R9.2, R10.2, R13.2, R14.2, U1.17 (VDDIO), U1.36 (VDDIO), U1.43 (VDDCORE), U1.44 (VDDIN), U2.5 (OUT), U4.3 (!WP(D2)), U4.7 (!HOLD(D3)), U4.8 (VCC), U6.5 (VCCA), U6.6 (OE)
5V: C12.+, C14.1, C15.2, D4.C, D5.C, R11.2, R12.2, U2.1 (IN), U2.3 (EN), U5.P$11 (VCC), U6.16 (VCCB)
!E19_CS: Q2.2 (S), R10.1, U1.28 (PA19(SER1:3+)_D12)
!E19_CS5V: Q2.3 (D), R12.1, U5.P$15 (!NSS)
!E19_RST: Q1.2 (S), R9.1, U1.22 (PA13(I2C/SER2:1+))
!E19_RST5V: Q1.3 (D), R11.1, U5.P$8 (!RST)
!RST: J6.8, J14.10 (!RESET), R1.1, S1.3 (2), S1.4 (2), U1.40 (!RESET!)
A0: J7.9, U1.3 (A0_PA02(AIN0/DAC))
A1: J7.8, U1.7 (A1_PB08(AIN2/SER4:0/TC4:0))
A2: J7.7, U1.8 (A2_PB09(AIN3/SER4:1/TC4:1))
A3: J7.6, U1.9 (A3_PA04(AIN4/REFB/SER0:0/TC0:0))
A4: J7.5, U1.10 (A4_PA05(AIN5/SER0:1/TC0:1))
ANT: J12.1, U5.P$19 (ANT)
D5: J6.7, U1.24 (PA15(XOUT/SER2:3+)_D5)
D8_!FLASH_CS: R7.1, U1.11 (D8_PA06(AIN6/SER0:2/TC1:0)), U4.1 (!CS)
D9: J6.3, U1.12 (D9_PA07(AIN7/SER0:3/TC1:1))
D10: U1.27 (PA18(SER1:2+)_D10), U6.9 (A7)
D11: U1.25 (PA16(I2C/SER1:0+)_D11), U6.10 (A8)
D13: R4.2, U1.26 (PA17(I2C/SER1:1+)_D13)
D+: J1.D+, U1.34 (PA25(SER3:3+))
D-: J1.D-, U1.33 (PA24(SER3:2+))
DIO05V: U5.P$7 (DIO0), U6.13 (B6)
DIO15V: U5.P$6 (DIO1), U6.12 (B7)
DIO25V: U5.P$5 (DIO2), U6.11 (B8)
E19_INT: U1.29 (PA20(SER5:2+)_D6), U6.8 (A6)
E19_RXEN: U1.38 (PB23(SER5:3+)), U6.7 (A5)
E19_RXEN5V: U5.P$17 (RXEN), U6.14 (B5)
E19_TXEN: U1.37 (PB22(SER5:2+)), U6.4 (A4)
E19_TXEN5V: U5.P$16 (TXEN), U6.17 (B4)
EEPROM_MISO: J6.6, U1.23 (PA14(XIN/SER2:2+)_D2), U4.2 (SO(D1))
EEPROM_MOSI: J6.4, U1.13 (PA08(I2C/AIN16/SER0:0+)_D4), U4.5 (SI(D0))
EEPROM_SCLK: J6.5, U1.14 (PA09(I2C/AIN17/SER0:1+)_D3), U4.6 (SCK)
GND: C1.1, C2.1, C3.1, C4.1, C5.1, C6.1, C7.1, C8.2, C9.-, C10.-, C11.2, C12.-, C13.1, C14.2, C15.1, D3.C, D6.C, J1.GND, J3.1, J4.1, J5.GND (GNDBREAK), J5.P$4 (GND), J7.1, J9.1, J9.2, J9.3, J9.4, J9.5, J9.6, J9.7, J9.8, J9.9, J10.1, J10.2, J10.3, J10.4, J10.5, J10.6, J10.7, J10.8, J10.9, J10.10, J11.1, J13.1, J14.3 (GND), J14.5 (GND), J14.9 (GNDDTCT), R6.1, S1.1, S1.2 (1), U1.5 (GNDANA), U1.18 (GND), U1.35 (GND), U1.42 (GND), U2.2 (GND), U4.4 (GND), U5.P$1 (GND), U5.P$9 (GND), U5.P$10 (GND), U5.P$18 (GND), U5.P$20 (GND), U5.P$21 (GND), U5.P$22 (GND), U6.15 (GND)
MISO: J7.2, U1.21 (PA12(I2C/SER2:0+)_MISO), U6.2 (A2)
MISO5V: U5.P$13 (MISO), U6.19 (B2)
MOSI: J7.3, U1.19 (PB10(SER4:2+)_MOSI), U6.3 (A3)
MOSI5V: U5.P$14 (MOSI), U6.18 (B3)
unnamed: D1.C, R2.2
unnamed: D2.C, R3.2
unnamed: D3.A, R4.1
unnamed: C1.2, U1.1 (PA00(XIN32/SER1:0/TC2:0)), Y1.P$2 (2)
unnamed: C2.2, U1.2 (PA01(XOUT32/SER1:1/TC2:1)), Y1.P$1 (1)
unnamed: D4.A, F1.1, JP1.1
unnamed: R5.1, R6.2, U3.1 (ADJ)
unnamed: D5.A, R5.2, U3.2 (OUT), U3.4 (OUT)
unnamed: D6.A, R8.1
RAW: J6.1, J8.1, S2.2, U3.3 (IN)
RXI: J6.10, U1.16 (PA11(AIN19/SER0:3+)_D0/RX)
RX_LED: R2.1, U1.48 (PB03(AIN11/SER5:1))
SCK: J7.4, U1.20 (PB11(SER4:3+)_SCK), U6.1 (A1)
SCK5V: U5.P$12 (SCK), U6.20 (B1)
SCL: J11.4, J13.4, R14.1, U1.32 (PA23(I2C/SER3:0+)_SCL)
SDA: J11.3, J13.3, R13.1, U1.31 (PA22(I2C/SER3:0+)_SDA)
SHLD: J1.SHIELD, J1.SHIELD2 (SHIELD), J1.SHIELD3 (SHIELD), J1.SHIELD4 (SHIELD), J1.SHIELD5 (SHIELD), J1.SHIELD6 (SHIELD), J1.SHIELD7 (SHIELD), J1.SHIELD8 (SHIELD), J1.SHIELD9 (SHIELD), J1.SHIELD10 (SHIELD)
SWDCLK: J14.4 (SWDCLK/TCK), U1.45 (PA30(SWCLK/SER1:2+))
SWDIO: J14.2 (SWDIO/TMS), U1.46 (PA31(SWDIO/SER1:3+))
TXO: J6.9, U1.15 (PA10(AIN18/SER0:2+)_D1/TX)
TX_LED: R3.1, U1.39 (PA27)
VBATT: C9.+, J3.2, J5.VIN0 (PWR), J8.2, S2.3 (S)
VDDANA: C7.2, L1.2, U1.6 (VDDANA)
V_USB: C3.2, C8.1, F1.2, J1.VBUS, J4.2, JP1.2

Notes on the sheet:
Solder this jumper if powering the board with VUSB and drawing more than 500 mA
500mA charging
VDDIN
VDDANA
Decoupling
SAMD21G
Elias Santistevan, Owen Lyke
x02
POWER
VUSB
FLASH MEMORY
E19-915MS1W
RESET
HEADERS/QWIIC
USB
PROGRAMMING HEADER
RX/TX LEDs
Max Voltage Input: 15VDC
Max Current Output: 800mA
Level Shifters
VIN 7-15V
Max Voltage Input: 7VDC
Max Voltage Input: 6VDC
Max Current Output: 600mA
When not using EEPROM you can use these pins as GPIOs D2-D4

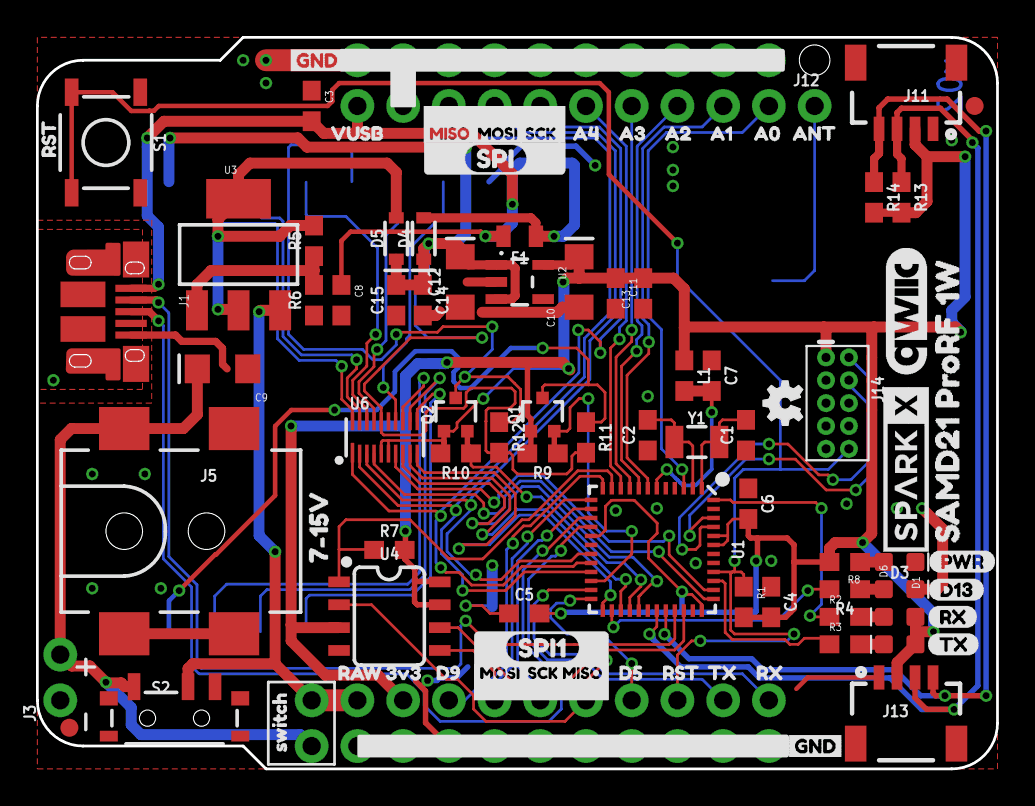
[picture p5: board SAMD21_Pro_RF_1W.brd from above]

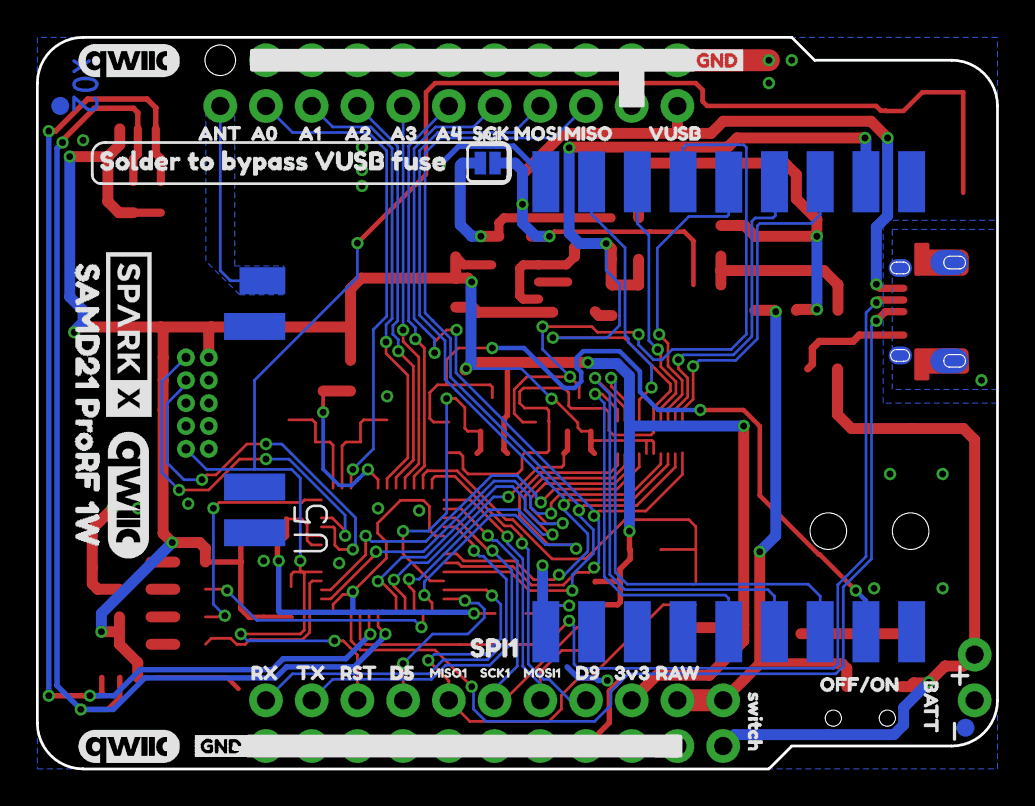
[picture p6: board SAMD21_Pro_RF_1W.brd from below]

Board: 2 copper layers, 53.3 x 40.6 mm, 134 parts (36 on the bottom side), 61 nets.

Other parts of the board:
U$1, U$14: VUSB7
U$2, U$10: MISO4
U$3, U$42: A43
U$4, U$43: A34
U$5, U$44: A25
U$6, U$45: A16
U$7, U$46: A07
U$8: SPI2
U$9, U$20: MOSI3
U$11, U$50: ANT11
U$12, U$17, U$38, U$62: GND0
U$13, U$28, U$41: RST2
U$15, U$16: D90
U$18, U$39: SCK5
U$19, U$73: RX2
U$21, U$65: SPI11
U$22: MISO17
U$23, U$53: 3V320
U$24, U$52: RAW21
U$25: 7#15V0
U$26, U$81: SAMD21_PRORF_1W5
U$27, U$37: SWITCH6
U$30, U$51: QWIIC_COPYRIGHT_MEDIUM
U$31: MOSI16
U$32: BATT25
U$33: D50
U$35: SOLDER_TO_BYPASS_VUSB_FUSE1
U$36: OFF#ON1
U$47: MISO8
U$48: MOSI9
U$49: SCK10
U$55: D514
U$57, U$69: TX3
U$58: SPARKX-MEDIUM
U$59: D130
U$60: SCK18
U$61: OSHW-LOGO-MINI
U$63: PWR-()-03
U$64, U$67: QWIIC_COPYRIGHT_SMALL
U$70: TX6
U$72: RX7

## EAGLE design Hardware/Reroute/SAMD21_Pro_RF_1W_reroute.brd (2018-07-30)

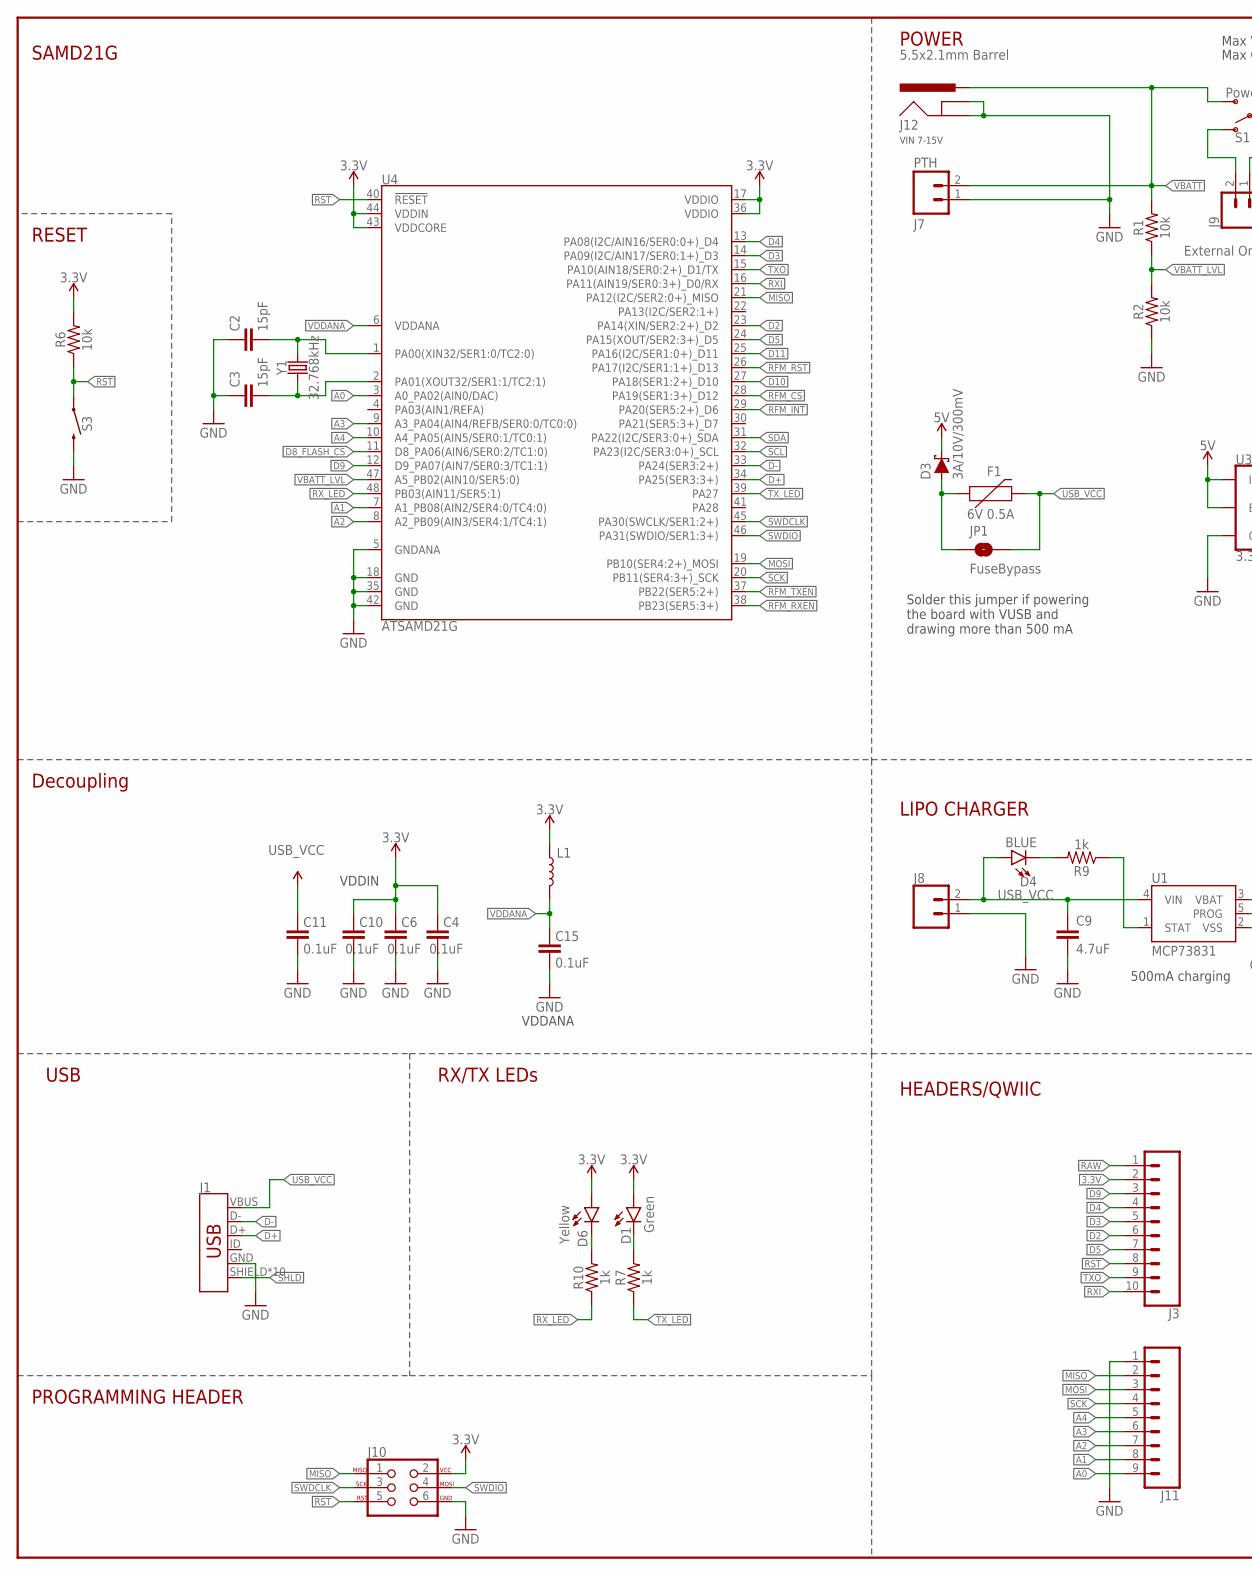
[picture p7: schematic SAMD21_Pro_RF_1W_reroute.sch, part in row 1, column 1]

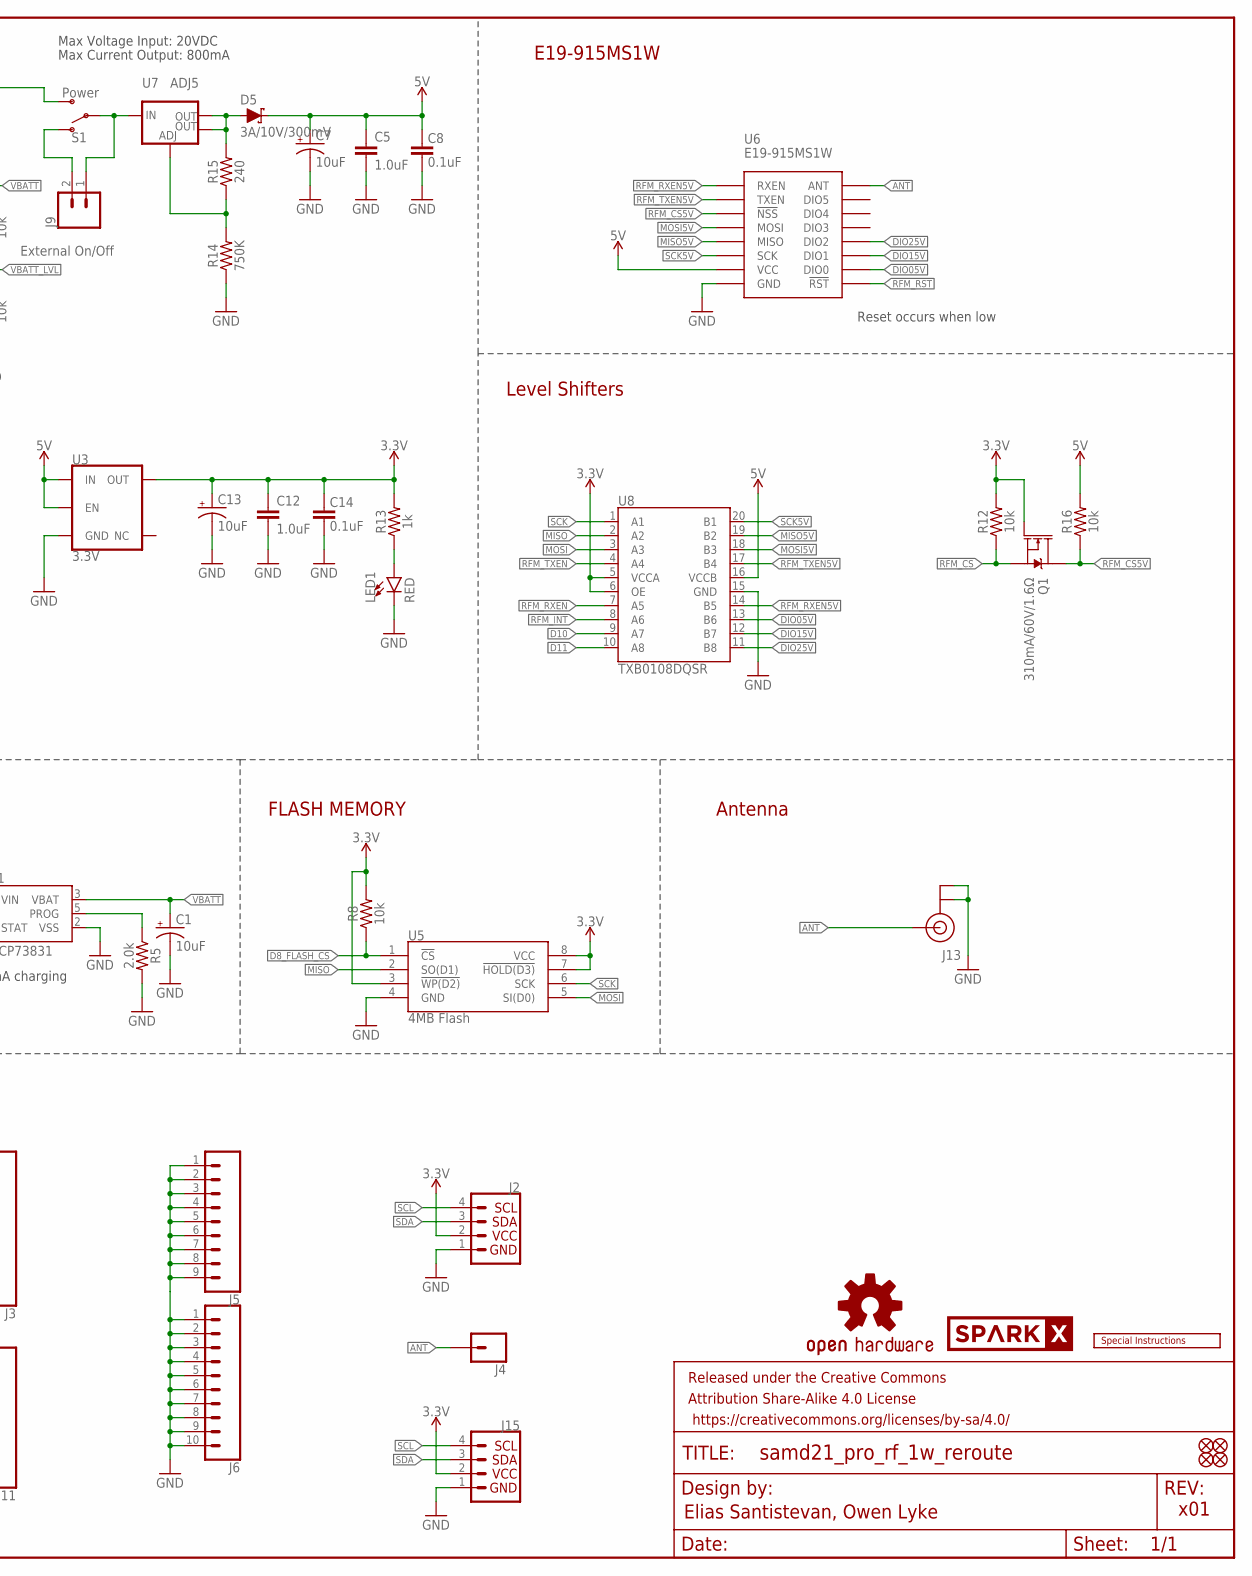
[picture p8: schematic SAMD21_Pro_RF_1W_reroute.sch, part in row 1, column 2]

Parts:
C1, C7, C13: 10uF; EIA3216
C2, C3: 15pF; 0603
C4, C6, C8, C10, C11, C14, C15: 0.1uF; 0603
C5, C12: 1.0uF; 0603
C9: 4.7uF; 0603
D1: Green; LED-0603
D3, D5: 3A/10V/300mV; SOD-323
D4: BLUE; LED-0603
D6: Yellow; LED-0603
F1: 6V 0.5A; 0805
FD1, FD2, FD3, FD4: FIDUCIAL1X2; FIDUCIAL-1X2
FRAME2: FRAME-LEDGER; CREATIVE_COMMONS
J1: USB_MICRO-B_HALF_PTH_MILL; USB-MICROB-PTH-MILL
J2, J15: QWIIC_CONNECTORJS-1MM; 1X04_1MM_RA
J3, J6: CONN_10NO_SILK_PTH_FEMALE; 1X10_NO_SILK
J4: CONN_01PTH_NO_SILK_YES_STOP; 1X01_NO_SILK
J5, J11: CONN_09NO_SILK; 1X09_NO_SILK
J7: PTH; 1X02_NO_SILK
J8: CONN_021X02_NO_SILK; 1X02_NO_SILK
J9: External On/Off; 1X02_NO_SILK
J10: AVR_SPI_PROG_3X2TESTPOINTS; 2X3_TEST_POINTS
J12: 5.5x2.1mm Barrel; POWER_JACK_SMD
J13: U.FL
JP1: FuseBypass; SMT-JUMPER_2_NO_SILK
L1: INDUCTORFB-30OHM; 0603
LED1: RED; LED-0603
LOGO1: OSHW-LOGOMINI; OSHW-LOGO-MINI
Q1: 310mA/60V/1.6Ω; SOT323
R1, R2, R6, R8, R12, R16: 10k; 0603
R5: 2.0k; 0603
R7, R9, R10, R13: 1k; 0603
R14: 750K; 0603
R15: 240; 0603
S1: Power; SWITCH_SPST_SMD_A
S3: MOMENTARY-SWITCH-SPST-SMD-RIGHT-ANGLE; TACTILE_SWITCH_SMD_RIGHT_ANGLE
U1: MCP73831; SOT23-5
U3: 3.3V; SOT23-5
U4: ATSAMD21G; QFN-48_NO_EXPOSED_PAD
U5: 4MB Flash; SO08
U6: E19-915MS1W
U7: ADJ5; SOT223
U8: TXB0108DQSR; UFDFN-20
U$26: SPECIAL_INSTRUCTIONS-ORDERING; ORDERING_INSTRUCTIONS
U$34: SPARKX-LOGO2; SPARKX-TINY
Y1: 32.768kHz; CRYSTAL-SMD-3.2X1.5MM

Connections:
3.3V: C4.2, C6.2, C10.2, C12.1, C13.+, C14.2, D1.A, D6.A, J2.2, J3.2, J10.2, J15.2, L1.1, Q1.1 (G), R6.2, R8.2, R12.2, R13.2, U3.5 (OUT), U4.17 (VDDIO), U4.36 (VDDIO), U4.43 (VDDCORE), U4.44 (VDDIN), U5.3 (!WP(D2)), U5.7 (!HOLD(D3)), U5.8 (VCC), U8.5 (VCCA), U8.6 (OE)
5V: C5.1, C7.+, C8.2, D3.C, D5.C, R16.2, U3.1 (IN), U3.3 (EN), U6.P$11 (VCC), U8.16 (VCCB)
!RFM_CS: Q1.2 (S), R12.1, U4.28 (PA19(SER1:3+)_D12)
!RFM_CS5V: Q1.3 (D), R16.1, U6.P$15 (!NSS)
!RST: J3.8, J10.5, R6.1, S3.1, U4.40 (!RESET!)
A0: J11.9, U4.3 (A0_PA02(AIN0/DAC))
A1: J11.8, U4.7 (A1_PB08(AIN2/SER4:0/TC4:0))
A2: J11.7, U4.8 (A2_PB09(AIN3/SER4:1/TC4:1))
A3: J11.6, U4.9 (A3_PA04(AIN4/REFB/SER0:0/TC0:0))
A4: J11.5, U4.10 (A4_PA05(AIN5/SER0:1/TC0:1))
ANT: J4.1, J13.FEED (SIGNAL), U6.P$19 (ANT)
CHARGE_STAT: R9.1, U1.1 (STAT)
D2: J3.6, U4.23 (PA14(XIN/SER2:2+)_D2)
D3: J3.5, U4.14 (PA09(I2C/AIN17/SER0:1+)_D3)
D4: J3.4, U4.13 (PA08(I2C/AIN16/SER0:0+)_D4)
D5: J3.7, U4.24 (PA15(XOUT/SER2:3+)_D5)
D8_!FLASH_CS: R8.1, U4.11 (D8_PA06(AIN6/SER0:2/TC1:0)), U5.1 (!CS)
D9: J3.3, U4.12 (D9_PA07(AIN7/SER0:3/TC1:1))
D10: U4.27 (PA18(SER1:2+)_D10), U8.9 (A7)
D11: U4.25 (PA16(I2C/SER1:0+)_D11), U8.10 (A8)
D+: J1.D+, U4.34 (PA25(SER3:3+))
D-: J1.D-, U4.33 (PA24(SER3:2+))
DIO05V: U6.P$7 (DIO0), U8.13 (B6)
DIO15V: U6.P$6 (DIO1), U8.12 (B7)
DIO25V: U6.P$5 (DIO2), U8.11 (B8)
GND: C1.-, C2.1, C3.1, C4.1, C5.2, C6.1, C7.-, C8.1, C9.2, C10.1, C11.1, C12.2, C13.-, C14.1, C15.1, J1.GND, J2.1, J5.1, J5.2, J5.3, J5.4, J5.5, J5.6, J5.7, J5.8, J5.9, J6.1, J6.2, J6.3, J6.4, J6.5, J6.6, J6.7, J6.8, J6.9, J6.10, J7.1, J8.1, J10.6, J11.1, J12.GND (GNDBREAK), J12.P$4 (GND), J13.1 (GND), J13.2 (GND), J15.1, LED1.C, R2.1, R5.2, R14.1, S3.2, U1.2 (VSS), U3.2 (GND), U4.5 (GNDANA), U4.18 (GND), U4.35 (GND), U4.42 (GND), U5.4 (GND), U6.P$1 (GND), U6.P$9 (GND), U6.P$10 (GND), U6.P$18 (GND), U6.P$20 (GND), U6.P$21 (GND), U6.P$22 (GND), U8.15 (GND)
MISO: J10.1, J11.2, U4.21 (PA12(I2C/SER2:0+)_MISO), U5.2 (SO(D1)), U8.2 (A2)
MISO5V: U6.P$13 (MISO), U8.19 (B2)
MOSI: J11.3, U4.19 (PB10(SER4:2+)_MOSI), U5.5 (SI(D0)), U8.3 (A3)
MOSI5V: U6.P$14 (MOSI), U8.18 (B3)
unnamed: D6.C, R10.2
unnamed: D1.C, R7.2
unnamed: C2.2, U4.1 (PA00(XIN32/SER1:0/TC2:0)), Y1.P$2 (2)
unnamed: C3.2, U4.2 (PA01(XOUT32/SER1:1/TC2:1)), Y1.P$1 (1)
unnamed: D4.C, R9.2
unnamed: J9.2, S1.1 (O)
unnamed: R5.1, U1.5 (PROG)
unnamed: D3.A, F1.1, JP1.1
unnamed: R14.2, R15.1, U7.1 (ADJ)
unnamed: D5.A, R15.2, U7.2 (OUT), U7.4 (OUT)
unnamed: LED1.A, R13.1
RAW: J3.1, J9.1, S1.2, U7.3 (IN)
RFM_INT: U4.29 (PA20(SER5:2+)_D6), U8.8 (A6)
RFM_RST: U4.26 (PA17(I2C/SER1:1+)_D13), U6.P$8 (!RST)
RFM_RXEN: U4.38 (PB23(SER5:3+)), U8.7 (A5)
RFM_RXEN5V: U6.P$17 (RXEN), U8.14 (B5)
RFM_TXEN: U4.37 (PB22(SER5:2+)), U8.4 (A4)
RFM_TXEN5V: U6.P$16 (TXEN), U8.17 (B4)
RXI: J3.10, U4.16 (PA11(AIN19/SER0:3+)_D0/RX)
RX_LED: R10.1, U4.48 (PB03(AIN11/SER5:1))
SCK: J11.4, U4.20 (PB11(SER4:3+)_SCK), U5.6 (SCK), U8.1 (A1)
SCK5V: U6.P$12 (SCK), U8.20 (B1)
SCL: J2.4, J15.4, U4.32 (PA23(I2C/SER3:0+)_SCL)
SDA: J2.3, J15.3, U4.31 (PA22(I2C/SER3:0+)_SDA)
SHLD: J1.SHIELD, J1.SHIELD2 (SHIELD), J1.SHIELD3 (SHIELD), J1.SHIELD4 (SHIELD), J1.SHIELD5 (SHIELD), J1.SHIELD6 (SHIELD), J1.SHIELD7 (SHIELD), J1.SHIELD8 (SHIELD), J1.SHIELD9 (SHIELD), J1.SHIELD10 (SHIELD)
SWDCLK: J10.3, U4.45 (PA30(SWCLK/SER1:2+))
SWDIO: J10.4, U4.46 (PA31(SWDIO/SER1:3+))
TXO: J3.9, U4.15 (PA10(AIN18/SER0:2+)_D1/TX)
TX_LED: R7.1, U4.39 (PA27)
USB_VCC: C9.1, C11.2, D4.A, F1.2, J1.VBUS, J8.2, JP1.2, U1.4 (VIN)
VBATT: C1.+, J7.2, J12.VIN0 (PWR), R1.2, S1.3 (S), U1.3 (VBAT)
VBATT_LVL: R1.1, R2.2, U4.47 (A5_PB02(AIN10/SER5:0))
VDDANA: C15.2, L1.2, U4.6 (VDDANA)

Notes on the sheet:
Solder this jumper if powering the board with VUSB and drawing more than 500 mA
500mA charging
VDDIN
VDDANA
Decoupling
SAMD21G
Elias Santistevan, Owen Lyke
x01
POWER
LIPO CHARGER
FLASH MEMORY
E19-915MS1W
RESET
HEADERS/QWIIC
USB
PROGRAMMING HEADER
Antenna
RX/TX LEDs
Reset occurs when low
Max Voltage Input: 20VDC
Max Current Output: 800mA
Level Shifters
VIN 7-15V

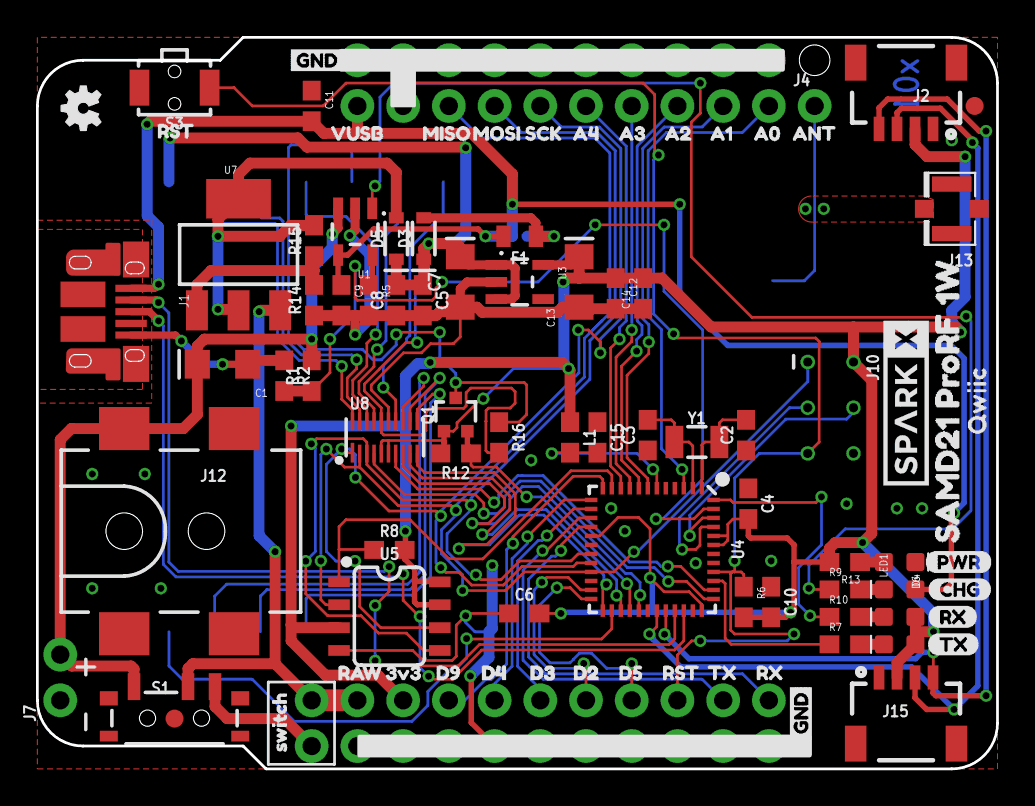
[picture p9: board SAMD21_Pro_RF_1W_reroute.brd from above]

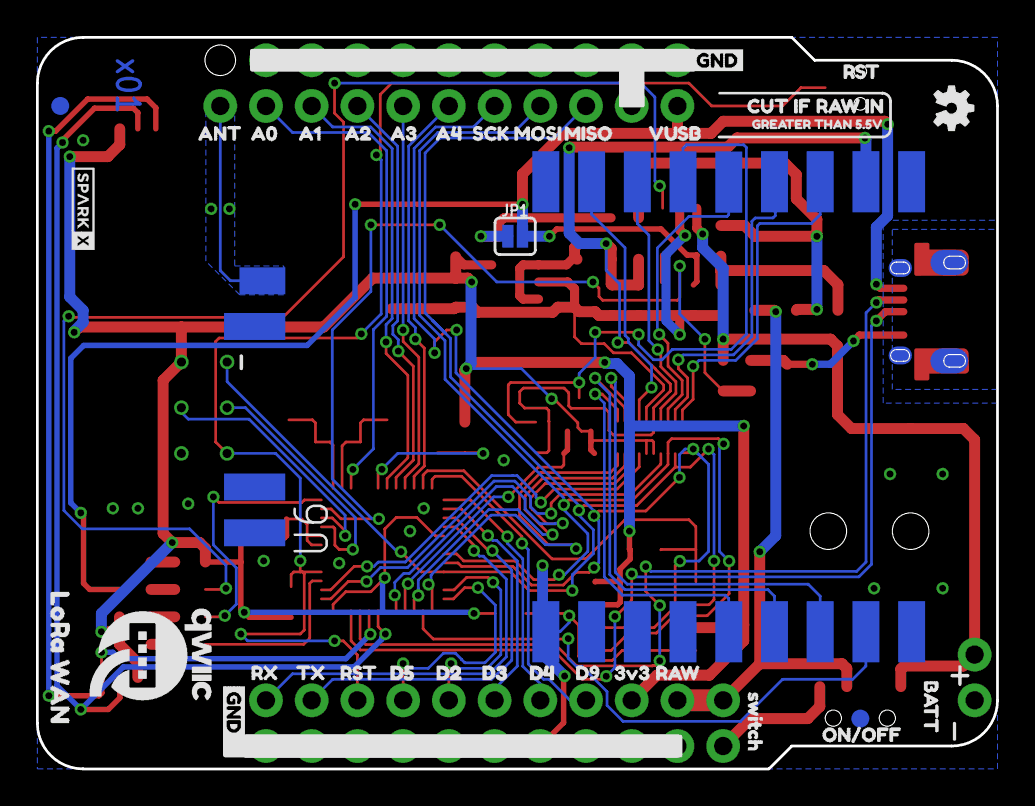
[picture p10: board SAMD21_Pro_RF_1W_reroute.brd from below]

Board: 2 copper layers, 53.3 x 40.6 mm, 133 parts (37 on the bottom side), 63 nets.

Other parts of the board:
U$1, U$14: VUSB7
U$2, U$18: D20
U$3, U$42: A43
U$4, U$43: A34
U$5, U$44: A25
U$6, U$45: A16
U$7, U$46: A07
U$8, U$47: MISO8
U$9, U$48: MOSI9
U$10, U$49: SCK10
U$11, U$50: ANT11
U$12, U$17, U$38, U$62: GND0
U$13, U$28, U$36, U$41: RST2
U$15, U$16: D90
U$19, U$73: RX2
U$20, U$21: D30
U$22, U$31: D40
U$23, U$53: 3V320
U$24, U$52: RAW21
U$25: LORA0
U$27, U$37: SWITCH6
U$30: QWIIC-LOGO-MEDIUM
U$32: BATT25
U$33: D50
U$35: WAN1
U$39: ON#OFF0
U$51: SPARKX-MEDIUM
U$55: D514
U$57, U$69: TX3
U$58: CUT_IF_RAW_IN0
U$59: GREATER_THAN_5#5V0
U$60: QWIIC-TEXT-04
U$61: OSHW-LOGO-MINI
U$63: PWR-()-03
U$65: CHG1
U$70: TX6
U$72: RX7
U$81: SAMD21_PRORF_1W5

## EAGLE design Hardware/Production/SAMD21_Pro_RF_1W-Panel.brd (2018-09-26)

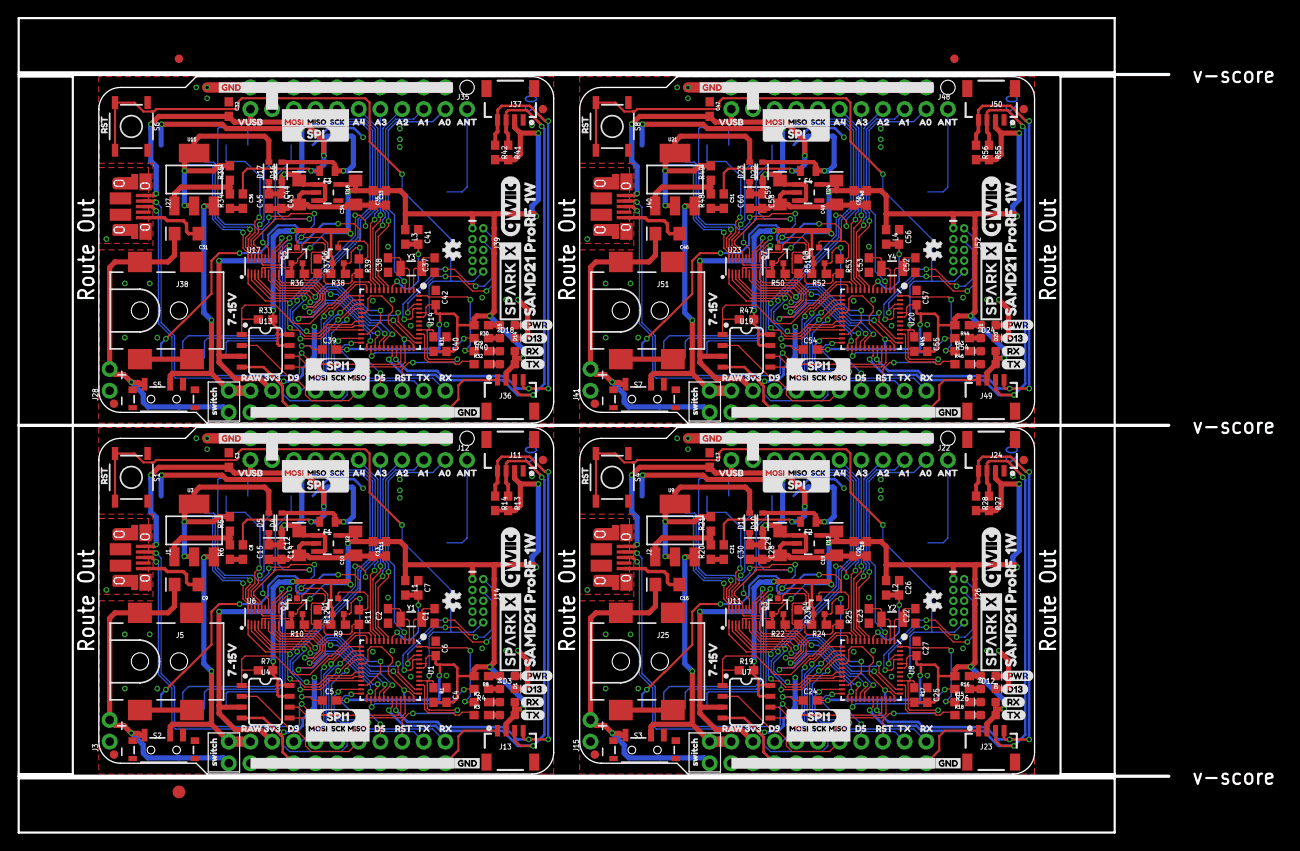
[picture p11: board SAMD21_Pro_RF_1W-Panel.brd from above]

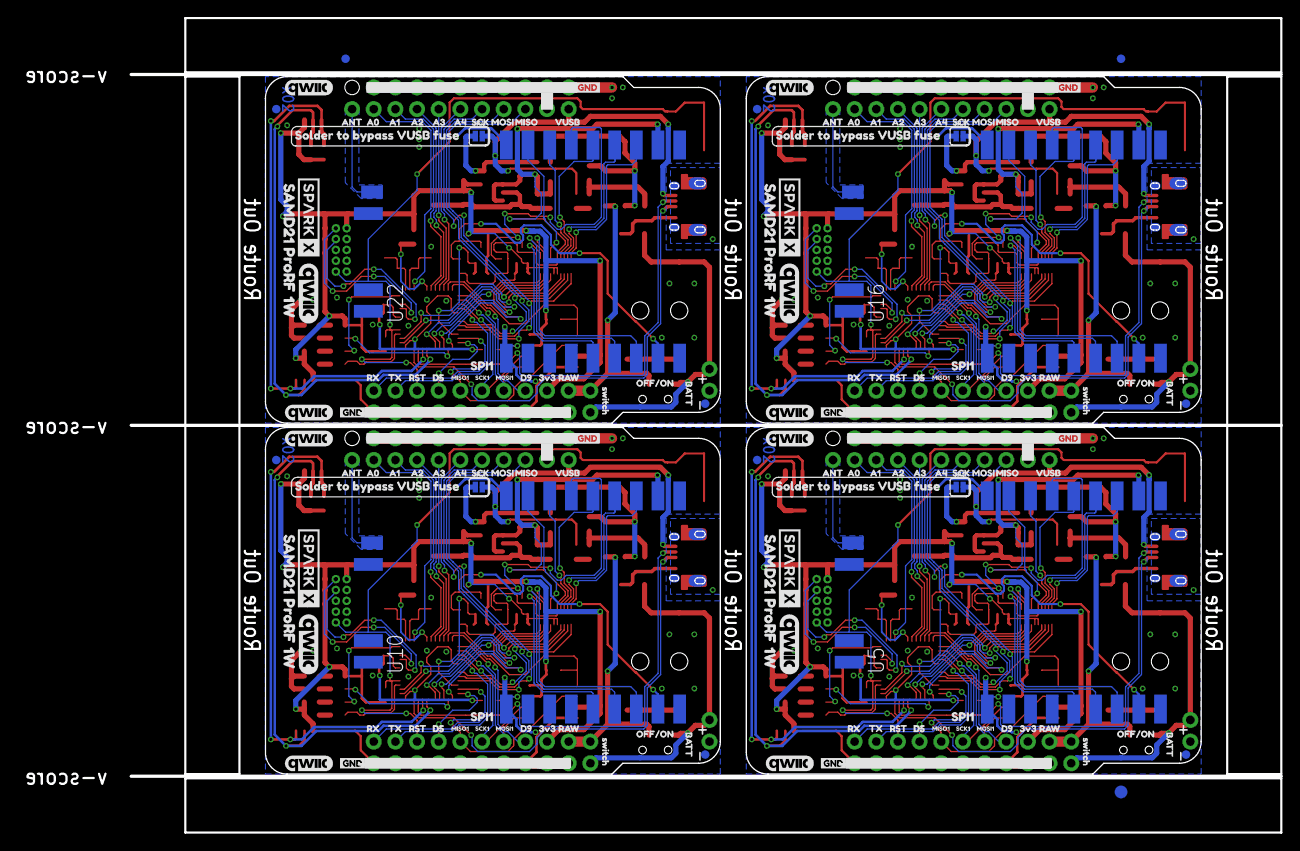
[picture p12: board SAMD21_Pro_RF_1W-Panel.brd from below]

Board: 2 copper layers, 134.9 x 95.5 mm, 538 parts (147 on the bottom side), 244 nets.

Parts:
C1, C2, C22, C23, C37, C38, C52, C53: 15pF; 0603
C3, C4, C5, C6, C7, C13, C15, C17, C20, C24, C25, C26, C27, C30, C32, C35, C39, C40, C41, C42, C45, C47, C50, C54, C55, C56, C57, C60: 0.1uF; 0603
C8, C21, C36, C51: 4.7uF; 0603
C9, C10, C12, C16, C19, C29, C31, C34, C44, C46, C49, C59: 10uF; EIA3216
C11, C14, C18, C28, C33, C43, C48, C58: 1.0uF; 0603
D1, D8, D14, D20: Yellow; LED-0603
D2, D7, D13, D19: Green; LED-0603
D3, D12, D18, D24: BLUE; LED-0603
D4, D5, D10, D11, D16, D17, D22, D23: 3A/10V/300mV; SOD-323
D6, D9, D15, D21: RED; LED-0603
E$1, E$2, E$3, E$4: FIDUCIAL-1X2
E$5, E$6: FIDUCIAL-1.5X3
F1, F2, F3, F4: 6V 0.5A; 0805
FD1, FD2, FD3, FD4, FD5, FD6, FD7, FD8, FD9, FD10, FD11, FD12, FD13, FD14, FD15, FD16: FIDUCIAL1X2; FIDUCIAL-1X2
J1, J2, J27, J40: USB-MICROB-PTH-MILL
J3, J15, J28, J41: PTH; 1X02_NO_SILK
J4, J16, J29, J42: 1X02_NO_SILK
J5, J25, J38, J51: 5.5x2.1mm Barrel; POWER_JACK_SMD
J6, J10, J18, J19, J31, J32, J44, J45: 1X10_NO_SILK
J7, J9, J20, J21, J33, J34, J46, J47: 1X09_NO_SILK
J8, J17, J30, J43: External On/Off; 1X02_NO_SILK
J11, J13, J23, J24, J36, J37, J49, J50: 1X04_1MM_RA
J12, J22, J35, J48: 1X01_NO_SILK
J14, J26, J39, J52: CORTEX_DEBUG_PTH; 2X5-PTH-1.27MM
JP1, JP2, JP3, JP4: FuseBypass; SMT-JUMPER_2_NO_SILK
L1, L2, L3, L4: 0603
Q1, Q2, Q3, Q4, Q5, Q6, Q7, Q8: 310mA/60V/1.6Ω; SOT323
R1, R7, R9, R10, R11, R12, R17, R19, R22, R23, R24, R25, R31, R33, R36, R37, R38, R39, R45, R47, R50, R51, R52, R53: 10k; 0603
R2, R3, R4, R8, R15, R16, R18, R26, R29, R30, R32, R40, R43, R44, R46, R54: 1k; 0603
R5, R21, R35, R49: 240; 0603
R6, R20, R34, R48: 750; 0603
R13, R14, R27, R28, R41, R42, R55, R56: 2.2k; 0603
S1, S4, S6, S8: MOMENTARY-SWITCH-SPST-SMD-5.2-REDUNDANT; TACTILE_SWITCH_SMD_5.2MM
S2, S3, S5, S7: Power; SWITCH_SPST_SMD_A
U1, U8, U14, U20: ATSAMD21G; QFN-48_NO_EXPOSED_PAD
U2, U12, U18, U24: 3.3V; SOT23-5
U3, U9, U15, U21: ADJ5; SOT223
U4, U7, U13, U19: 4MB Flash; SO08
U5, U10, U16, U22: E19-915MS1W
U6, U11, U17, U23: TXB0108DQSR; UFDFN-20
U$1, U$14, U$108, U$109, U$175, U$176, U$242, U$243: VUSB7
U$2, U$10, U$121, U$123, U$188, U$190, U$255, U$257: MISO4
U$3, U$29, U$42, U$82, U$135, U$149, U$202, U$216: A43
U$4, U$40, U$43, U$83, U$136, U$150, U$203, U$217: A34
U$5, U$44, U$54, U$84, U$137, U$151, U$204, U$218: A25
U$6, U$45, U$56, U$85, U$138, U$152, U$205, U$219: A16
U$7, U$46, U$66, U$86, U$139, U$153, U$206, U$220: A07
U$8, U$119, U$186, U$253: SPI2
U$9, U$20, U$120, U$125, U$187, U$192, U$254, U$259: MOSI3
U$11, U$50, U$68, U$90, U$140, U$157, U$207, U$224: ANT11
U$12, U$17, U$38, U$62, U$71, U$79, U$93, U$102, U$141, U$147, U$160, U$169, U$208, U$214, U$227, U$236: GND0
U$13, U$28, U$41, U$74, U$77, U$80, U$142, U$145, U$148, U$209, U$212, U$215: RST2
U$15, U$16, U$100, U$101, U$167, U$168, U$234, U$235: D90
U$18, U$39, U$122, U$124, U$189, U$191, U$256, U$258: SCK5
U$19, U$73, U$98, U$103, U$165, U$170, U$232, U$237: RX2
U$21, U$65, U$126, U$127, U$193, U$194, U$260, U$261: SPI11
U$22, U$128, U$195, U$262: MISO17
U$23, U$53, U$75, U$92, U$143, U$159, U$210, U$226: 3V320
U$24, U$52, U$76, U$91, U$144, U$158, U$211, U$225: RAW21
U$25, U$112, U$179, U$246: 7#15V0
U$26, U$81, U$107, U$115, U$174, U$182, U$241, U$249: SAMD21_PRORF_1W5
U$27, U$37, U$110, U$111, U$177, U$178, U$244, U$245: SWITCH6
U$30, U$51, U$133, U$134, U$200, U$201, U$267, U$268: QWIIC_COPYRIGHT_MEDIUM
U$31, U$129, U$196, U$263: MOSI16
U$32, U$78, U$146, U$213: BATT25
U$33, U$105, U$172, U$239: D50
U$34, U$114, U$181, U$248: SPARKX-LOGO4; SPARKX-MEDIUM
U$35, U$113, U$180, U$247: SOLDER_TO_BYPASS_VUSB_FUSE1
U$36, U$118, U$185, U$252: OFF#ON1
U$47, U$87, U$154, U$221: MISO8
U$48, U$88, U$155, U$222: MOSI9
U$49, U$89, U$156, U$223: SCK10
U$55, U$99, U$166, U$233: D514
U$57, U$69, U$95, U$104, U$162, U$171, U$229, U$238: TX3
U$58, U$116, U$183, U$250: SPARKX-MEDIUM
U$59, U$117, U$184, U$251: D130
U$60, U$130, U$197, U$264: SCK18
U$61, U$106, U$173, U$240: OSHW-LOGO-MINI
U$63, U$94, U$161, U$228: PWR-()-03
U$64, U$67, U$131, U$132, U$198, U$199, U$265, U$266: QWIIC_COPYRIGHT_SMALL
U$70, U$96, U$163, U$230: TX6
U$72, U$97, U$164, U$231: RX7
Y1, Y2, Y3, Y4: 32.768kHz; CRYSTAL-SMD-3.2X1.5MM

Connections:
3.3V: C4.2, C5.2, C6.2, C10.+, C11.1, C13.2, D1.A, D2.A, J6.2, J11.2, J13.2, J14.1, L1.1, Q1.1, Q2.1, R1.2, R7.2, R8.2, R9.2, R10.2, R13.2, R14.2, U1.17, U1.36, U1.43, U1.44, U2.5, U4.3, U4.7, U4.8, U6.5, U6.6
3.3V1: C18.1, C19.+, C20.2, C24.2, C25.2, C27.2, D7.A, D8.A, J18.2, J23.2, J24.2, J26.1, L2.1, Q3.1, Q4.1, R16.2, R17.2, R19.2, R22.2, R24.2, R27.2, R28.2, U7.3, U7.7, U7.8, U8.17, U8.36, U8.43, U8.44, U11.5, U11.6, U12.5
3.3V2: C33.1, C34.+, C35.2, C39.2, C40.2, C42.2, D13.A, D14.A, J31.2, J36.2, J37.2, J39.1, L3.1, Q5.1, Q6.1, R30.2, R31.2, R33.2, R36.2, R38.2, R41.2, R42.2, U13.3, U13.7, U13.8, U14.17, U14.36, U14.43, U14.44, U17.5, U17.6, U18.5
3.3V3: C48.1, C49.+, C50.2, C54.2, C55.2, C57.2, D19.A, D20.A, J44.2, J49.2, J50.2, J52.1, L4.1, Q7.1, Q8.1, R44.2, R45.2, R47.2, R50.2, R52.2, R55.2, R56.2, U19.3, U19.7, U19.8, U20.17, U20.36, U20.43, U20.44, U23.5, U23.6, U24.5
5V: C12.+, C14.1, C15.2, D4.C, D5.C, R11.2, R12.2, U2.1, U2.3, U5.P$11, U6.16
5V1: C28.1, C29.+, C30.2, D10.C, D11.C, R23.2, R25.2, U10.P$11, U11.16, U12.1, U12.3
5V2: C43.1, C44.+, C45.2, D16.C, D17.C, R37.2, R39.2, U16.P$11, U17.16, U18.1, U18.3
5V3: C58.1, C59.+, C60.2, D22.C, D23.C, R51.2, R53.2, U22.P$11, U23.16, U24.1, U24.3
!E19_CS: Q2.2, R10.1, U1.28
!E19_CS1: Q3.2, R22.1, U8.28
!E19_CS2: Q5.2, R36.1, U14.28
!E19_CS3: Q7.2, R50.1, U20.28
!E19_CS5V: Q2.3, R12.1, U5.P$15
!E19_CS5V1: Q3.3, R23.1, U10.P$15
!E19_CS5V2: Q5.3, R37.1, U16.P$15
!E19_CS5V3: Q7.3, R51.1, U22.P$15
!E19_RST: Q1.2, R9.1, U1.22
!E19_RST1: Q4.2, R24.1, U8.22
!E19_RST2: Q6.2, R38.1, U14.22
!E19_RST3: Q8.2, R52.1, U20.22
!E19_RST5V: Q1.3, R11.1, U5.P$8
!E19_RST5V1: Q4.3, R25.1, U10.P$8
!E19_RST5V2: Q6.3, R39.1, U16.P$8
!E19_RST5V3: Q8.3, R53.1, U22.P$8
!RST: J6.8, J14.10, R1.1, S1.3, S1.4, U1.40
!RST1: J18.8, J26.10, R17.1, S4.3, S4.4, U8.40
!RST2: J31.8, J39.10, R31.1, S6.3, S6.4, U14.40
!RST3: J44.8, J52.10, R45.1, S8.3, S8.4, U20.40
A0: J7.9, U1.3
A1: J7.8, U1.7
A2: J7.7, U1.8
A3: J7.6, U1.9
A4: J7.5, U1.10
A5: J21.9, U8.3
A6: J21.8, U8.7
A7: J21.7, U8.8
A8: J21.6, U8.9
A9: J21.5, U8.10
A10: J34.9, U14.3
A11: J34.8, U14.7
A12: J34.7, U14.8
A13: J34.6, U14.9
A14: J34.5, U14.10
A15: J47.9, U20.3
A16: J47.8, U20.7
A17: J47.7, U20.8
A18: J47.6, U20.9
A19: J47.5, U20.10
ANT: J12.1, U5.P$19
ANT1: J22.1, U10.P$19
ANT2: J35.1, U16.P$19
ANT3: J48.1, U22.P$19
D1: U8.27, U11.9
D2: U8.25, U11.10
D3: J18.7, U8.24
D4: J18.3, U8.12
D5: J6.7, U1.24
D6: R26.2, U8.26
D7: U14.27, U17.9
D8: U14.25, U17.10
D8_!FLASH_CS: R7.1, U1.11, U4.1
D8_!FLASH_CS1: R19.1, U7.1, U8.11
D8_!FLASH_CS2: R33.1, U13.1, U14.11
D8_!FLASH_CS3: R47.1, U19.1, U20.11
D9: J6.3, U1.12
D10: U1.27, U6.9
D11: U1.25, U6.10
D12: J31.7, U14.24
D13: R4.2, U1.26
D14: J31.3, U14.12
D15: R40.2, U14.26
D16: U20.27, U23.9
D17: U20.25, U23.10
D18: J44.7, U20.24
D19: J44.3, U20.12
D20: R54.2, U20.26
D+: J1.D+, U1.34
D+1: J2.D+, U8.34
D+2: J27.D+, U14.34
D+3: J40.D+, U20.34
D-: J1.D-, U1.33
D-1: J2.D-, U8.33
D-2: J27.D-, U14.33
D-3: J40.D-, U20.33
DIO05V: U5.P$7, U6.13
DIO05V1: U10.P$7, U11.13
DIO05V2: U16.P$7, U17.13
DIO05V3: U22.P$7, U23.13
DIO15V: U5.P$6, U6.12
DIO15V1: U10.P$6, U11.12
DIO15V2: U16.P$6, U17.12
DIO15V3: U22.P$6, U23.12
DIO25V: U5.P$5, U6.11
DIO25V1: U10.P$5, U11.11
DIO25V2: U16.P$5, U17.11
DIO25V3: U22.P$5, U23.11
E19_INT: U1.29, U6.8
E19_INT1: U8.29, U11.8
E19_INT2: U14.29, U17.8
E19_INT3: U20.29, U23.8
E19_RXEN: U1.38, U6.7
E19_RXEN1: U8.38, U11.7
E19_RXEN2: U14.38, U17.7
E19_RXEN3: U20.38, U23.7
E19_RXEN5V: U5.P$17, U6.14
E19_RXEN5V1: U10.P$17, U11.14
E19_RXEN5V2: U16.P$17, U17.14
E19_RXEN5V3: U22.P$17, U23.14
E19_TXEN: U1.37, U6.4
E19_TXEN1: U8.37, U11.4
E19_TXEN2: U14.37, U17.4
E19_TXEN3: U20.37, U23.4
E19_TXEN5V: U5.P$16, U6.17
E19_TXEN5V1: U10.P$16, U11.17
E19_TXEN5V2: U16.P$16, U17.17
E19_TXEN5V3: U22.P$16, U23.17
EEPROM_MISO: J6.6, U1.23, U4.2
EEPROM_MISO1: J18.6, U7.2, U8.23
EEPROM_MISO2: J31.6, U13.2, U14.23
EEPROM_MISO3: J44.6, U19.2, U20.23
EEPROM_MOSI: J6.4, U1.13, U4.5
EEPROM_MOSI1: J18.4, U7.5, U8.13
EEPROM_MOSI2: J31.4, U13.5, U14.13
EEPROM_MOSI3: J44.4, U19.5, U20.13
EEPROM_SCLK: J6.5, U1.14, U4.6
EEPROM_SCLK1: J18.5, U7.6, U8.14
EEPROM_SCLK2: J31.5, U13.6, U14.14
EEPROM_SCLK3: J44.5, U19.6, U20.14
GND: C1.1, C2.1, C3.1, C4.1, C5.1, C6.1, C7.1, C8.2, C9.-, C10.-, C11.2, C12.-, C13.1, C14.2, C15.1, D3.C, D6.C, J1.GND, J3.1, J4.1, J5.GND, J5.P$4, J7.1, J9.1, J9.2, J9.3, J9.4, J9.5, J9.6, J9.7, J9.8, J9.9, J10.1, J10.2, J10.3, J10.4, J10.5, J10.6, J10.7, J10.8, J10.9, J10.10, J11.1, J13.1, J14.3, J14.5, J14.9, R6.1, S1.1, S1.2, U1.5, U1.18, U1.35, U1.42, U2.2, U4.4, U5.P$1, U5.P$9, U5.P$10, U5.P$18, U5.P$20, U5.P$21, U5.P$22, U6.15
GND1: C16.-, C17.1, C18.2, C19.-, C20.1, C21.2, C22.1, C23.1, C24.1, C25.1, C26.1, C27.1, C28.2, C29.-, C30.1, D9.C, D12.C, J2.GND, J15.1, J16.1, J19.1, J19.2, J19.3, J19.4, J19.5, J19.6, J19.7, J19.8, J19.9, J19.10, J20.1, J20.2, J20.3, J20.4, J20.5, J20.6, J20.7, J20.8, J20.9, J21.1, J23.1, J24.1, J25.GND, J25.P$4, J26.3, J26.5, J26.9, R20.1, S4.1, S4.2, U7.4, U8.5, U8.18, U8.35, U8.42, U10.P$1, U10.P$9, U10.P$10, U10.P$18, U10.P$20, U10.P$21, U10.P$22, U11.15, U12.2
GND2: C31.-, C32.1, C33.2, C34.-, C35.1, C36.2, C37.1, C38.1, C39.1, C40.1, C41.1, C42.1, C43.2, C44.-, C45.1, D15.C, D18.C, J27.GND, J28.1, J29.1, J32.1, J32.2, J32.3, J32.4, J32.5, J32.6, J32.7, J32.8, J32.9, J32.10, J33.1, J33.2, J33.3, J33.4, J33.5, J33.6, J33.7, J33.8, J33.9, J34.1, J36.1, J37.1, J38.GND, J38.P$4, J39.3, J39.5, J39.9, R34.1, S6.1, S6.2, U13.4, U14.5, U14.18, U14.35, U14.42, U16.P$1, U16.P$9, U16.P$10, U16.P$18, U16.P$20, U16.P$21, U16.P$22, U17.15, U18.2
GND3: C46.-, C47.1, C48.2, C49.-, C50.1, C51.2, C52.1, C53.1, C54.1, C55.1, C56.1, C57.1, C58.2, C59.-, C60.1, D21.C, D24.C, J40.GND, J41.1, J42.1, J45.1, J45.2, J45.3, J45.4, J45.5, J45.6, J45.7, J45.8, J45.9, J45.10, J46.1, J46.2, J46.3, J46.4, J46.5, J46.6, J46.7, J46.8, J46.9, J47.1, J49.1, J50.1, J51.GND, J51.P$4, J52.3, J52.5, J52.9, R48.1, S8.1, S8.2, U19.4, U20.5, U20.18, U20.35, U20.42, U22.P$1, U22.P$9, U22.P$10, U22.P$18, U22.P$20, U22.P$21, U22.P$22, U23.15, U24.2
MISO: J7.2, U1.21, U6.2
MISO1: J21.2, U8.21, U11.2
MISO2: J34.2, U14.21, U17.2
MISO3: J47.2, U20.21, U23.2
MISO5V: U5.P$13, U6.19
MISO5V1: U10.P$13, U11.19
MISO5V2: U16.P$13, U17.19
MISO5V3: U22.P$13, U23.19
MOSI: J7.3, U1.19, U6.3
MOSI1: J21.3, U8.19, U11.3
MOSI2: J34.3, U14.19, U17.3
MOSI3: J47.3, U20.19, U23.3
MOSI5V: U5.P$14, U6.18
MOSI5V1: U10.P$14, U11.18
MOSI5V2: U16.P$14, U17.18
MOSI5V3: U22.P$14, U23.18
unnamed: D1.C, R2.2
unnamed: D2.C, R3.2
unnamed: D3.A, R4.1
unnamed: D9.A, R16.1
unnamed: D8.C, R15.2
unnamed: C1.2, U1.1, Y1.P$2
unnamed: C2.2, U1.2, Y1.P$1
unnamed: D7.C, R18.2
unnamed: C22.2, U8.1, Y2.P$2
unnamed: C23.2, U8.2, Y2.P$1
unnamed: R20.2, R21.1, U9.1
unnamed: D4.A, F1.1, JP1.1
unnamed: R5.1, R6.2, U3.1
unnamed: D5.A, R5.2, U3.2, U3.4
unnamed: D10.A, F2.1, JP2.1
unnamed: D11.A, R21.2, U9.2, U9.4
unnamed: D12.A, R26.1
unnamed: D15.A, R30.1
unnamed: D14.C, R29.2
unnamed: D13.C, R32.2
unnamed: C37.2, U14.1, Y3.P$2
unnamed: C38.2, U14.2, Y3.P$1
unnamed: R34.2, R35.1, U15.1
unnamed: D16.A, F3.1, JP3.1
unnamed: D17.A, R35.2, U15.2, U15.4
unnamed: D18.A, R40.1
unnamed: D21.A, R44.1
unnamed: D20.C, R43.2
unnamed: D19.C, R46.2
unnamed: C52.2, U20.1, Y4.P$2
unnamed: C53.2, U20.2, Y4.P$1
unnamed: R48.2, R49.1, U21.1
unnamed: D22.A, F4.1, JP4.1
unnamed: D23.A, R49.2, U21.2, U21.4
unnamed: D24.A, R54.1
unnamed: D6.A, R8.1
RAW: J6.1, J8.1, S2.2, U3.3
RAW1: J17.1, J18.1, S3.2, U9.3
RAW2: J30.1, J31.1, S5.2, U15.3
RAW3: J43.1, J44.1, S7.2, U21.3
RXI: J6.10, U1.16
RXI1: J18.10, U8.16
RXI2: J31.10, U14.16
RXI3: J44.10, U20.16
RX_LED: R2.1, U1.48
RX_LED1: R15.1, U8.48
RX_LED2: R29.1, U14.48
RX_LED3: R43.1, U20.48
SCK: J7.4, U1.20, U6.1
SCK1: J21.4, U8.20, U11.1
SCK2: J34.4, U14.20, U17.1
SCK3: J47.4, U20.20, U23.1
SCK5V: U5.P$12, U6.20
SCK5V1: U10.P$12, U11.20
SCK5V2: U16.P$12, U17.20
SCK5V3: U22.P$12, U23.20
SCL: J11.4, J13.4, R14.1, U1.32
SCL1: J23.4, J24.4, R28.1, U8.32
SCL2: J36.4, J37.4, R42.1, U14.32
SCL3: J49.4, J50.4, R56.1, U20.32
SDA: J11.3, J13.3, R13.1, U1.31
SDA1: J23.3, J24.3, R27.1, U8.31
SDA2: J36.3, J37.3, R41.1, U14.31
SDA3: J49.3, J50.3, R55.1, U20.31
SHLD: J1.SHIELD, J1.SHIELD2, J1.SHIELD3, J1.SHIELD4, J1.SHIELD5, J1.SHIELD6, J1.SHIELD7, J1.SHIELD8, J1.SHIELD9, J1.SHIELD10
SHLD1: J2.SHIELD, J2.SHIELD2, J2.SHIELD3, J2.SHIELD4, J2.SHIELD5, J2.SHIELD6, J2.SHIELD7, J2.SHIELD8, J2.SHIELD9, J2.SHIELD10
SHLD2: J27.SHIELD, J27.SHIELD2, J27.SHIELD3, J27.SHIELD4, J27.SHIELD5, J27.SHIELD6, J27.SHIELD7, J27.SHIELD8, J27.SHIELD9, J27.SHIELD10
SHLD3: J40.SHIELD, J40.SHIELD2, J40.SHIELD3, J40.SHIELD4, J40.SHIELD5, J40.SHIELD6, J40.SHIELD7, J40.SHIELD8, J40.SHIELD9, J40.SHIELD10
SWDCLK: J14.4, U1.45
SWDCLK1: J26.4, U8.45
SWDCLK2: J39.4, U14.45
SWDCLK3: J52.4, U20.45
SWDIO: J14.2, U1.46
SWDIO1: J26.2, U8.46
SWDIO2: J39.2, U14.46
SWDIO3: J52.2, U20.46
TXO: J6.9, U1.15
TXO1: J18.9, U8.15
TXO2: J31.9, U14.15
TXO3: J44.9, U20.15
TX_LED: R3.1, U1.39
TX_LED1: R18.1, U8.39
TX_LED2: R32.1, U14.39
TX_LED3: R46.1, U20.39
USB_VCC: C3.2, C8.1, F1.2, J1.VBUS, J4.2, JP1.2
USB_VCC1: C17.2, C21.1, F2.2, J2.VBUS, J16.2, JP2.2
USB_VCC2: C32.2, C36.1, F3.2, J27.VBUS, J29.2, JP3.2
USB_VCC3: C47.2, C51.1, F4.2, J40.VBUS, J42.2, JP4.2
VBATT: C9.+, J3.2, J5.VIN0, J8.2, S2.3
VBATT1: C16.+, J15.2, J17.2, J25.VIN0, S3.3
VBATT2: C31.+, J28.2, J30.2, J38.VIN0, S5.3
VBATT3: C46.+, J41.2, J43.2, J51.VIN0, S7.3
VDDANA: C7.2, L1.2, U1.6
VDDANA1: C26.2, L2.2, U8.6
VDDANA2: C41.2, L3.2, U14.6
VDDANA3: C56.2, L4.2, U20.6

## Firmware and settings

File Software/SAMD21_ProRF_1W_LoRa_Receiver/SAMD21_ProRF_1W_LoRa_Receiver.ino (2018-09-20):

/*
 * SAMD21_ProRF_1W_LoRa_Receiver
 * 
 * This example uses the source code from Sandeep Mistry's LoRa library (https://github.com/sandeepmistry/arduino-LoRa)
 * to receive point-to-point (P2P) LoRa packets. For the easiest use you should run the SAMD21_ProRF_1W_LoRa_Sender 
 * sketch on another ProRF 1W board as the transmitter.
 * 
 * License: Originally under MIT license.
 */
#include <SPI.h>
#include "LoRa.h" // Get the library here: (https://github.com/sandeepmistry/arduino-LoRa)

/* 
This sketch comes with a modified LoRa.h file that includes pin definitions for the 1W SAMD21 ProRF. 
If you do not have those definitions then they are re-listed here.

#define LORA_DEFAULT_SPI           SPI
//#define LORA_DEFAULT_SPI_FREQUENCY 8E6 
#define LORA_DEFAULT_SPI_FREQUENCY 500000 
#define LORA_DEFAULT_SS_PIN        12
#define LORA_DEFAULT_RESET_PIN     13
#define LORA_DEFAULT_DIO0_PIN      6

*/

#define TXEN_PIN 30
#define RXEN_PIN 31

uint16_t C0 = 0;            // Bytes to use in computing the checksum
uint16_t C1 = 0;    

uint32_t timenow = 0;     
uint32_t lastmillis = 0;

struct PC{                  // "Packet Counter" structure definition
  uint32_t bad = 0;
  uint32_t good = 0;
};

PC packetCounter;           // A packet counter to use

void setup() {
  SerialUSB.begin(115200);
  while(!SerialUSB){};    // Make sure we get to read the title text
  SerialUSB.println("SAMD21 ProRF 1W - LoRa Receiver");

  pinMode(TXEN_PIN, OUTPUT);                      // Setup the pins that control the 1W amplifiers
  pinMode(RXEN_PIN, OUTPUT);                      // Without these lines the RSSI will be greatly reduced
  digitalWrite(TXEN_PIN, LOW);
  digitalWrite(RXEN_PIN, HIGH);

  while(!LoRa.begin(915E6)) {                     // Try to start the module
    SerialUSB.println("Starting LoRa failed!");
    delay(500);
  }
}

void loop() {
  int packetSize = LoRa.parsePacket();
  if (packetSize) {
    handlePacket();   // If a packet was received then check it out
  }
}


void handlePacket()
{
  C0 = 0; // Reset the checksum calculation bytes
  C1 = 0;

  // Compute checksum and print received characters
  SerialUSB.print("Received packet '");
  while (LoRa.available()) {
    char c = (char)LoRa.read();
    SerialUSB.print(c);
    C0 = (C0 + c) % 255;    // Using Fletcher's 16-bit checksum:  https://en.wikipedia.org/wiki/Fletcher%27s_checksum
    C1 = (C1 + C0) % 255;
  }
  
  // print RSSI of packet
  int16_t thisRSSI = LoRa.packetRssi();
  SerialUSB.print("' with RSSI ");
  SerialUSB.println(thisRSSI);
  
  // Compute the checksum result
  uint16_t CB0 = ((C0 + C1) % 255);
  uint16_t CB1 = ((C0 + CB0) % 255);

  if(CB0 || CB1)              // CB0 and CB1 both evaluate to 0 when the checksum is good
  { 
    packetCounter.bad += 1; 
  }
  else
  { 
    packetCounter.good += 1; 
  }

  SerialUSB.print(", Total Good: "); 
  SerialUSB.print(packetCounter.good);
  SerialUSB.print(", Total Bad: ");
  SerialUSB.print(packetCounter.bad);
  SerialUSB.println();
}

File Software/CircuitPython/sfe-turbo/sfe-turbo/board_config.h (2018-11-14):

#ifndef BOARD_CONFIG_H
#define BOARD_CONFIG_H

#define __SAMD21G18A__ 1

#define VENDOR_NAME "SparkFun Electronics"
#define PRODUCT_NAME "SparkFun RedBoard Turbo"
#define VOLUME_LABEL "TURBOBOOT"
#define INDEX_URL "https://www.sparkfun.com/products/13912"
#define BOARD_ID "SAMD21G18A-SparkFun-RedBoard-Turbo-v0"

#define USB_VID 0x1B4F
#define USB_PID 0x0015

#define LED_PIN PIN_PA17
#define LED_TX_PIN PIN_PA27
#define LED_RX_PIN PIN_PB31

// 8/2018
// Until the repo is updated ... 
//
// There is an issue in the multiplexing for the neopixel
// The file neopixel.h needs the TURBO BOARD USB VID & PID
// added to the section that deals with this issue for Adafruit
//
// This is needed or the UF2 bootloader won't indicate it's state
// using the neopixel (green - connected to computer, red - connected to power)
//
// Basicall modify the #define to include a check for SFE Turbo (around line 70)
// The values are:
//  ((USB_VID == 0x1B4F) && (USB_PID == 0x0015))

#define BOARD_NEOPIXEL_PIN PIN_PA30
#define BOARD_NEOPIXEL_COUNT 1


#endif

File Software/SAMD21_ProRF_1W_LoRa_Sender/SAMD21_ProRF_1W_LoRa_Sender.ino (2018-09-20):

/*
 * SAMD21_ProRF_1W_LoRa_Receiver
 * 
 * This example uses the source code from Sandeep Mistry's LoRa library (https://github.com/sandeepmistry/arduino-LoRa)
 * to send point-to-point (P2P) LoRa packets. For the easiest use you should run the SAMD21_ProRF_1W_LoRa_Receiver 
 * sketch on another ProRF 1W board as the reciever.
 * 
 * License: Originally under MIT license.
 */
#include <SPI.h>
#include "LoRa.h" // Get the library here: (https://github.com/sandeepmistry/arduino-LoRa)

/* 
This sketch comes with a modified LoRa.h file that includes pin definitions for the 1W SAMD21 ProRF. 
If you do not have those definitions then they are re-listed here.

#define LORA_DEFAULT_SPI           SPI
//#define LORA_DEFAULT_SPI_FREQUENCY 8E6 
#define LORA_DEFAULT_SPI_FREQUENCY 500000 
#define LORA_DEFAULT_SS_PIN        12
#define LORA_DEFAULT_RESET_PIN     13
#define LORA_DEFAULT_DIO0_PIN      6

*/

#define TXEN_PIN 30     
#define RXEN_PIN 31
#define TEST_LENGTH 25    // Choose the total number of characters to send in each packet

int counter = 0;          // Counts the number of messages sent

uint16_t C0 = 0;          // Used in calculation of the checksum, to be verified by the receiver
uint16_t C1 = 0;

uint32_t timenow = 0;
uint32_t lastmillis = 0;

void setup() {
  SerialUSB.begin(115200);
  while(!SerialUSB){};
  SerialUSB.println("SAMD21 ProRF 1W - LoRa Sender");

  randomSeed(analogRead(0));  // Provide a random seed

  pinMode(TXEN_PIN, OUTPUT);      // Enable the 1W amplifier output
  pinMode(RXEN_PIN, OUTPUT);      // Without doing so the outgoing signal will be very weak
  digitalWrite(TXEN_PIN, HIGH);
  digitalWrite(RXEN_PIN, LOW);

  while (!LoRa.begin(915E6)) {
    SerialUSB.println("Starting LoRa failed!");
    delay(500);
  }
}

void loop() {
  SerialUSB.print("Sending packet: ");
  SerialUSB.print(counter);
  SerialUSB.print(", time since last send: ");

  timenow = millis();
  SerialUSB.println(timenow-lastmillis);
  lastmillis = timenow;


  // send packet
  LoRa.beginPacket();
  C0 = 0; 
  C1 = 0;
  for(uint8_t indi = 0; indi < TEST_LENGTH-2; indi++) // In this loop we choose random uppercase characters to send
  {                                                   // Additionally we compute Fletcher's 16-bit checksum (https://en.wikipedia.org/wiki/Fletcher%27s_checksum)
    char c = random(65,91);
    LoRa.write(c);
    C0 = (C0 + c) % 255;
    C1 = (C1 + C0) % 255;
  }
  uint16_t CB0 = 255 - ((C0 + C1) % 255);
  uint16_t CB1 = 255 - ((C0 + CB0) % 255);
  LoRa.write((uint8_t)(CB0 & 0xFF));
  LoRa.write((uint8_t)(CB1 & 0xFF));
  LoRa.endPacket();

  counter++;
  
  delay(500);
}

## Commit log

2018-07-19 Moved to hardware
    [SAMD21_Pro_RF_1W.brd, SAMD21_Pro_RF_1W.sch]
2018-07-20 Intermediate save
    [SAMD21_Pro_RF_1W.brd]
2018-07-20 Routed all wires
    [SAMD21_Pro_RF_1W.brd]
2018-07-20 Almost done
    ToDo: Ask for guidance on antenna traces, double check on if the same chip is used (to know how to connect DIO pins), get board/schem review, order
    [SAMD21_Pro_RF_1W.brd]
2018-07-20 Logging off
    [SAMD21_Pro_RF_1W.brd]
2018-07-23 Updates from board review
    [Board_Design_Checklist.xls, Board_Design_Checklist_SAMD21_ProRF_1W_X01.xls, SAMD21_Pro_RF_1W.brd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]
2018-07-24 Increased power trace width
    [SAMD21_Pro_RF_1W.brd]
2018-07-25 Updated power supply in schematic
    [SAMD21_Pro_RF_1W.brd, SAMD21_Pro_RF_1W.sch]
2018-07-26 Started a re-route
    [SAMD21_Pro_RF_1W.brd, SAMD21_Pro_RF_1W.sch, SAMD21_Pro_RF_1W_reroute.brd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]
2018-07-30 Finalized hardware
    [SAMD21_Pro_RF_1W.brd, SAMD21_Pro_RF_1W.sch, SAMD21_Pro_RF_1W_reroute.brd]
2018-08-22 Small changes
    [SAMD21_Pro_RF_1W.brd]
2018-08-31 Don't remember
    [SAMD21_Pro_RF_1W.brd]
2018-09-20 Finalizing things
    [SAMD21_Pro_RF_1W.brd, SAMD21_Pro_RF_1W.sch]
2018-09-21 Organize, add test data and parser
    [bigduck.csv]
2018-09-26 x02 ready for order
    [SAMD21_Pro_RF_1W-Panel.GBL, SAMD21_Pro_RF_1W-Panel.GBO, SAMD21_Pro_RF_1W-Panel.GBP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]
2018-10-03 Brought libraries into spec
    [SAMD21_Pro_RF_1W.brd, SAMD21_Pro_RF_1W.sch]
2018-10-25 Fixed silkscreen of "SPI" on top side
    [SAMD21_Pro_RF_1W.brd, SAMD21_Pro_RF_1W.sch]
2018-11-14 Add partial support for Circuit/MicroPython

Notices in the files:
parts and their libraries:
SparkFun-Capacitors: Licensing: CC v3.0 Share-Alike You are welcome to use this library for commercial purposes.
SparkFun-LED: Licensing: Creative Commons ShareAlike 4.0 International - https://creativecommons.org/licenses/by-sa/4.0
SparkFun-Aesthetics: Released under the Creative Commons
